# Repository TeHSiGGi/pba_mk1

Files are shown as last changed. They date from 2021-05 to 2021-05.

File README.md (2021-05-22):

# PBA MK1

## Introduction

The **P**ortable **B**luetooth **A**mp MK1 is the first iteration of a portable bluetooth amplifier.

The goal was to design a universal base platform for designing bluetooth speaker in a range of small to large power.

The amplifier is meant to be powered by LiPo batteries.

## Repository structure

```text
/pba:mk1
  /docs             # Documentation repository
  /eagle            # Contains eagle files
  /gerber           # Contains gerber board files
  /pdf              # Contains PDF versions of the schematics 
```

## Technical specification

### Power Supply

The power supply provides different voltages for digital and analog purpose.

It provides the following rails:

- `D33` - 3.3V 0.25A Digital - for digital logic and bluetooth module
- `A75` - 7.5V 0.10A Analog - for analog audio processing
- `D120` - 12V 1.00A Digital - Control voltage for Class-D amplifier
- `VAMP` - VBAT - 30V 3.00A - Amplification voltage for Class-D amplifier

The `D33` rail is constantly enabled and provides power for the bluetooth module.

All other rails are enabled on demand by the bluetooth module, via the `EN` signal.

As regulators for all rails expect `VAMP` `LMR50410` are used.

The `VAMP` rail can be varied between `VBAT` and 30V. This is provided by using a `LM5122` boost converter, that will be enabled on demand. If not required, the `LM5122` will go into passthrough mode and disable the boost action. The boost action is controlled via a separate `LVL` signal.

The power supply also provides the capability to charge and use a 4S LiPo battery. Please note: The power supply does **not** provide any balancing or protection circuitry. Those things must be included in your 4S LiPo battery pack.

As charging controller a `LTC4006-6` is used, which incorporates all necessary functionality.
The power supply used to charge the LiPo battery is a 19V external power supply. The input current is limited to 3.07A.

Charging current is limited to 2.00A and the charging timer is configured to approx. 2 hours.

There is currently **no** NTC readout configured in the charging circuit.

As a charger supply, I recommend the use of generic laptop chargers with 19V and 3.54A - they are widely available, reliable and cheap.

### Amplifier and DAC

As amplifiers there are two `TPA3245` used in this project.

The first of them is driven by directly by the `CSR8675` bluetooth chip DAC outputs, using a BTL configuration for two output channels.

The second amplifier is configured in a PBTL configuration and is driven by a `PCM5102` DAC.

The first amplifier should be used for full-range or dedicated mid/migh-range speakers, whereas the second amplifier with its PBTL configuration is meant to drive low-range/subwoofer speakers, since due to its configuration it is able to deliver more current and drive speakers with low impedances.

All analog signals are used differentially to reduce noise and hum. Between the differential DAC output and amplifier inputs there are `TS914` adding amplification to the signals for additional volume.

The amplifiers will automatically be enabled, if music is playing. This is controlled by the `CSR8675` using the `AMP_EN` signal.

There is an additional level detection circuit that will switch the amplifier supply voltage by setting the `LVL` signal to `high`. This allows the amplifier chips to run at a lower voltage for moderate volumes and have enough headroom for high volume music playback. The usage of a higher voltage also allows for better use of higher impedance speakers, such as 8-16Ohms.

The threshold of the level detection can be configured via a potentiometer on the amplifier board.

### Bluetooth

As for bluetooth, the `CSR8675` in form of `BTM-875` modules is used.

That chip provides the following functionality:

- Bluetooth 4.0+ compliance
- Stereo differential analogue audio inputs (used as line-in)
- Stereo differential analogue audio outputs (driving `TPA3245` in BTL configuration)
- I²S output (driving `PCM5102` for second `TPA3245` in PBTL configuration)
- LED and Button GPIOs (3 LEDs and 8 GPIOs are exposed)
- GPIO control for enabling external circuitry (enabling power with `EN` and amplifiers with `AMP_EN`)
- Kalimba DSP (used for crossover and DSP audio processing)
- True Wireless Stereo (can link two amplifiers together playing music in sync)

Software used on the `CSR8675` is configured using the ADK in version 4.1.35.

### Architecture

#### Audio signal paths

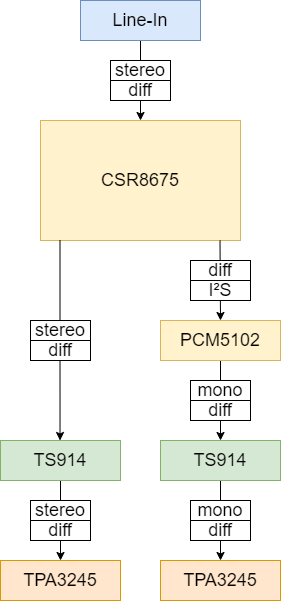
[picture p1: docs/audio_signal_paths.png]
Audio Signal Paths


#### Power paths

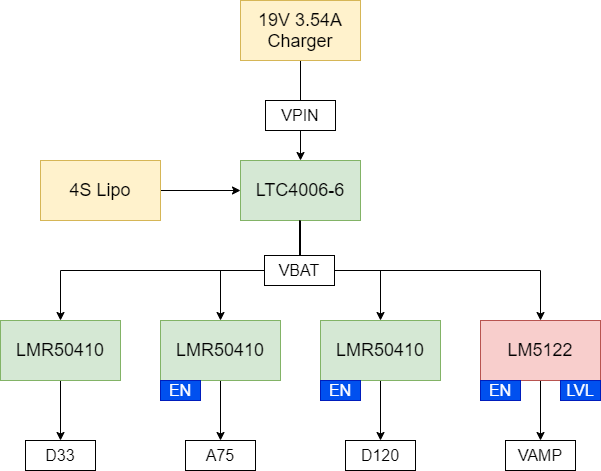
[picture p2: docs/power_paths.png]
Power Paths


#### GPIO to function mapping

|GPIO|Function|Description|
|--|--|--|
|LED0|User interface LED|Can be used to display status messages.|
|LED1|User interface LED|Can be used to display status messages.|
|LED2|User interface LED|Can be used to display status messages.|
|PIO0|User interface GPIO|Can be used to connect a button for user interaction.|
|PIO1|User interface GPIO|Can be used to connect a button for user interaction.|
|PIO2|User interface GPIO|Can be used to connect a button for user interaction.|
|PIO3|User interface GPIO|Can be used to connect a button for user interaction.|
|PIO4|User interface GPIO|Can be used to connect a button for user interaction.|
|PIO5|User interface GPIO|Can be used to connect a button for user interaction.|
|PIO6|User interface GPIO|Can be used to connect a button for user interaction.|
|PIO7|User interface GPIO|Can be used to connect a button for user interaction.|
|PWR|User interface GPIO|Can be used to connect a button for user interaction.|
|PIO10|DETECT|Used to detect plugged in line-in source.|
|PIO11|AMP_EN|Used to enable amplifiers when music is playing.|
|PIO12|EN|Used to enable the power supply.|
|PIO15|I²S DAC enable|Used to enable the external I²S dac if music is playing.|

### Miscellaneous

Schematics and layouts are created using Eagle.

Gerber files provided have been used to create first batch of boards and working instances of the PBA MK1.

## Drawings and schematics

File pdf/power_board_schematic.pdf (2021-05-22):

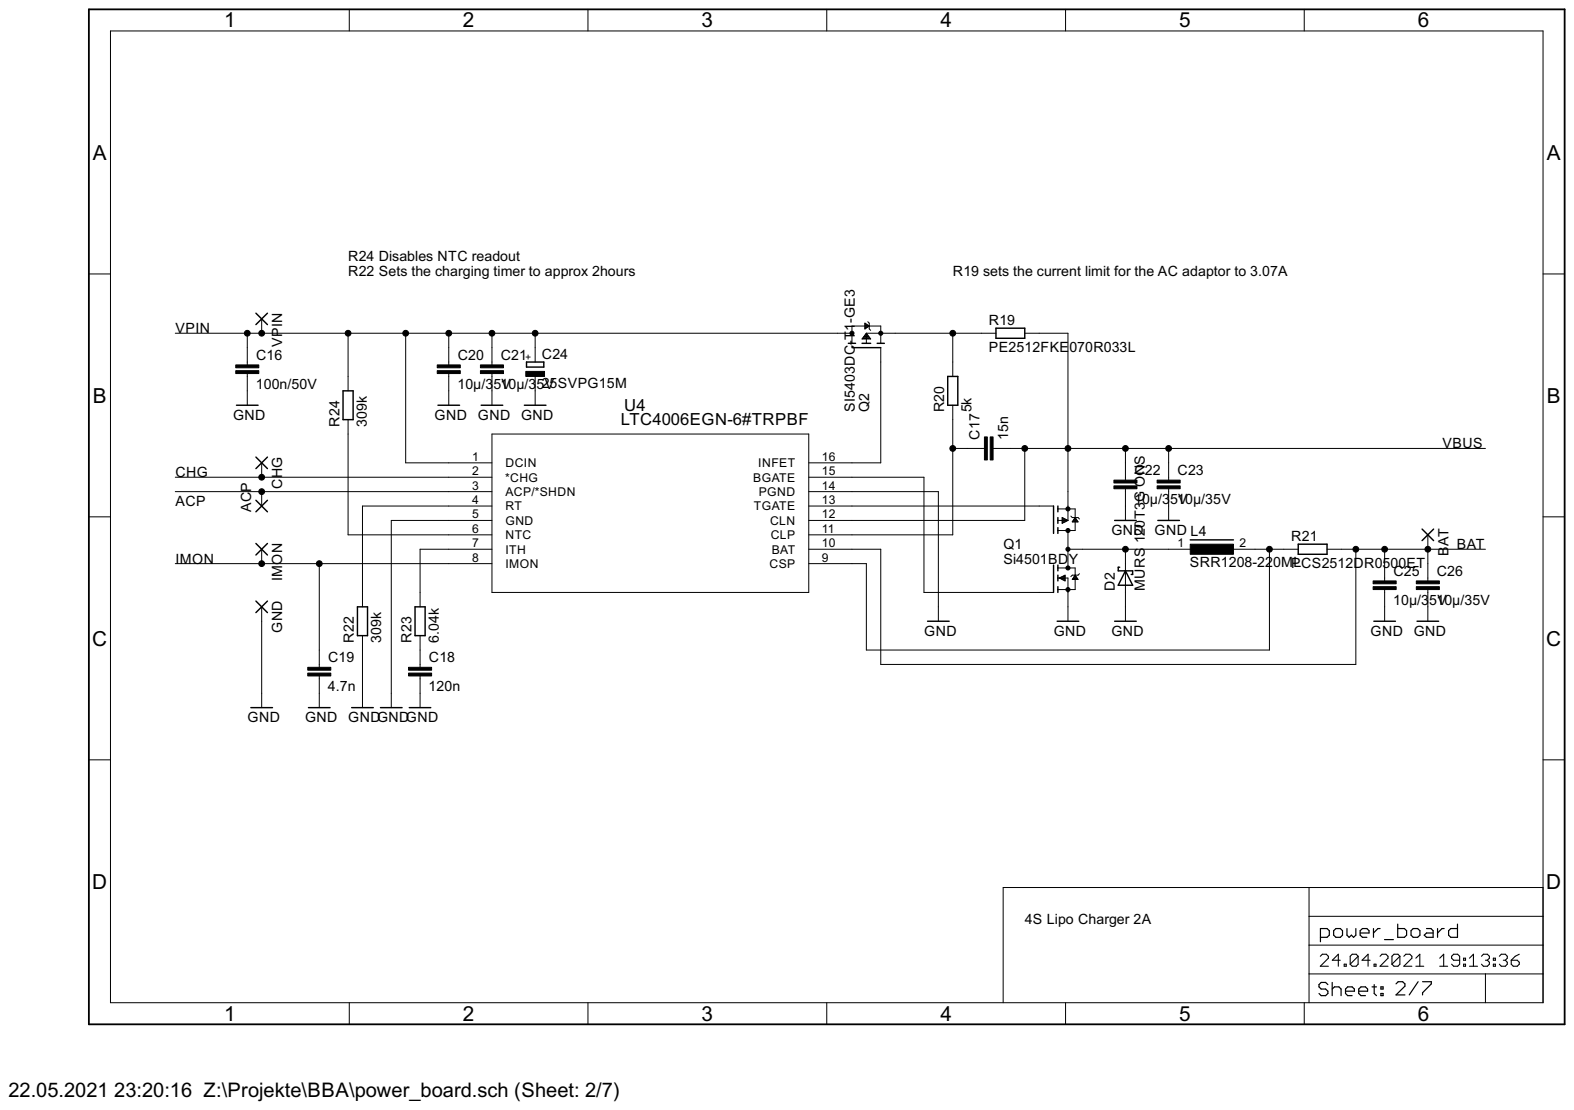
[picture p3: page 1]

13 PGND
12 TGATE

22.05.2021 23:20:16 Z:\Projekte\BBA\power_board.sch (Sheet: 2/7)

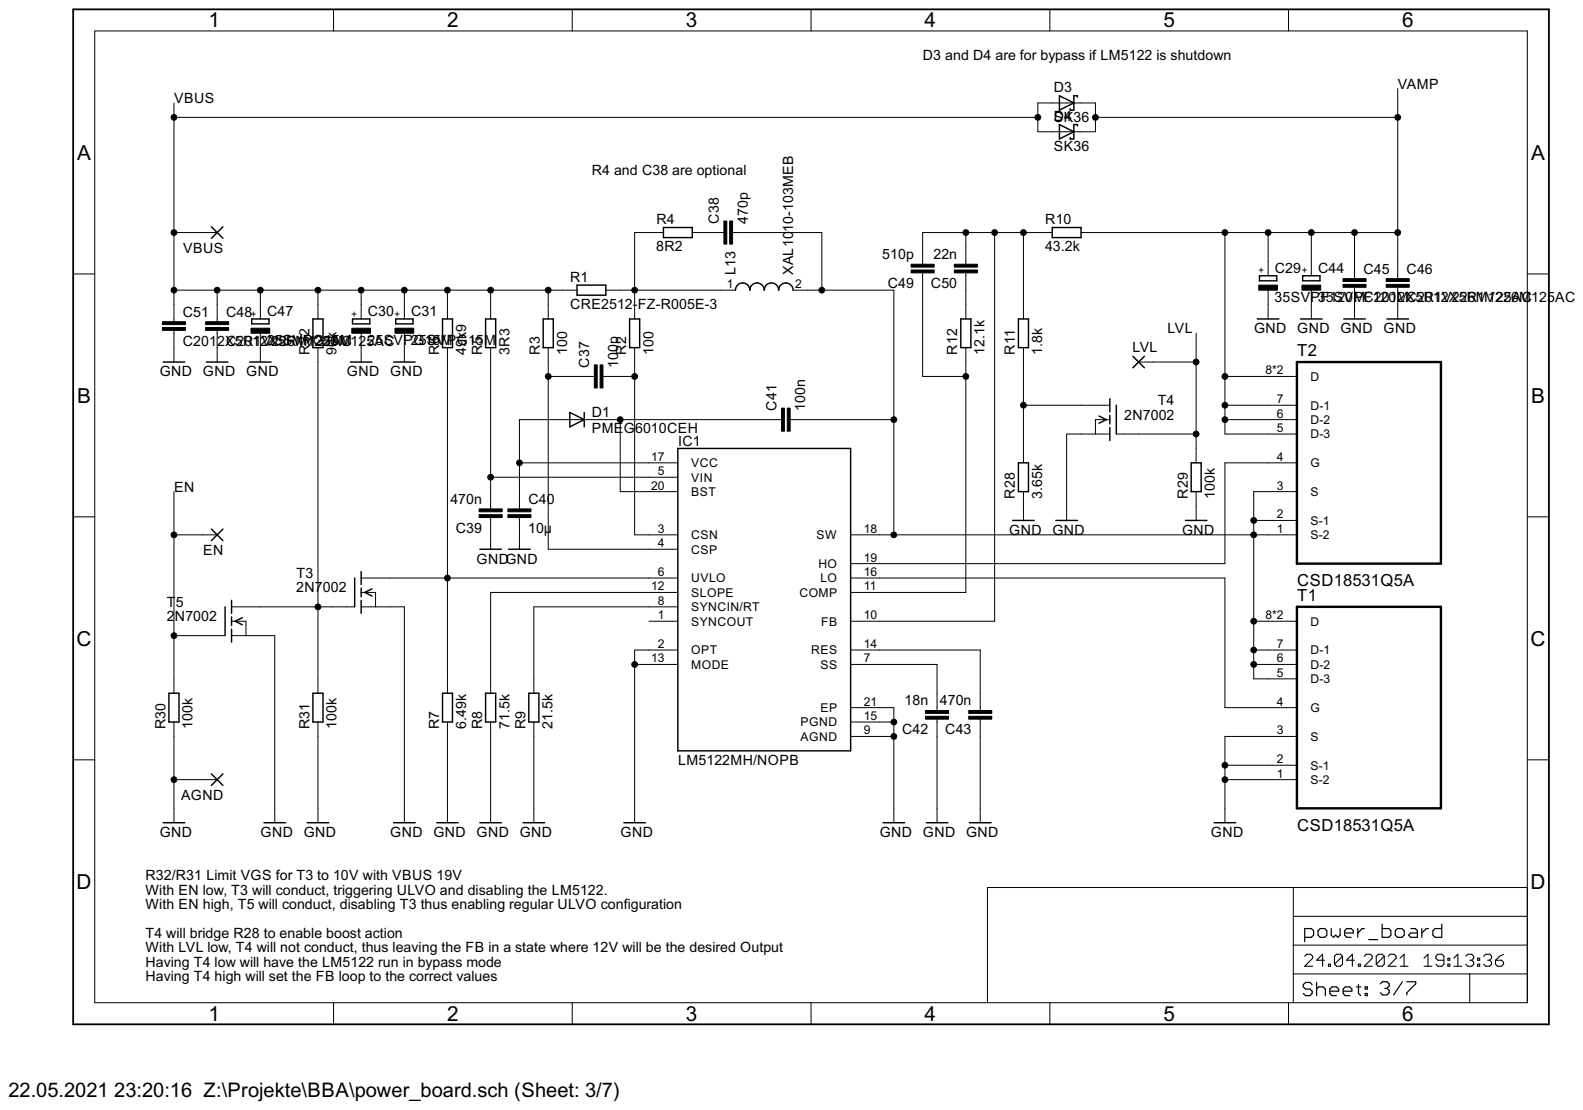
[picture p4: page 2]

D3 and D4 are for bypass if LM5122 is shutdown

GND

R32/R31 Limit VGS for T3 to 10V with VBUS 19V
With EN low, T3 will conduct, triggering ULVO and disabling the LM5122. T4 will bridge R28 to enable boost action With LVL low, T4 will not conduct, thus leaving the FB in a state where 12V will be the desired Output
Having T4 low will have the LM5122 run in bypass mode Having T4 high will set the FB loop to the correct values With EN high, T5 will conduct, disabling T3 thus enabling regular ULVO configuration

22.05.2021 23:20:16 Z:\Projekte\BBA\power_board.sch (Sheet: 3/7)

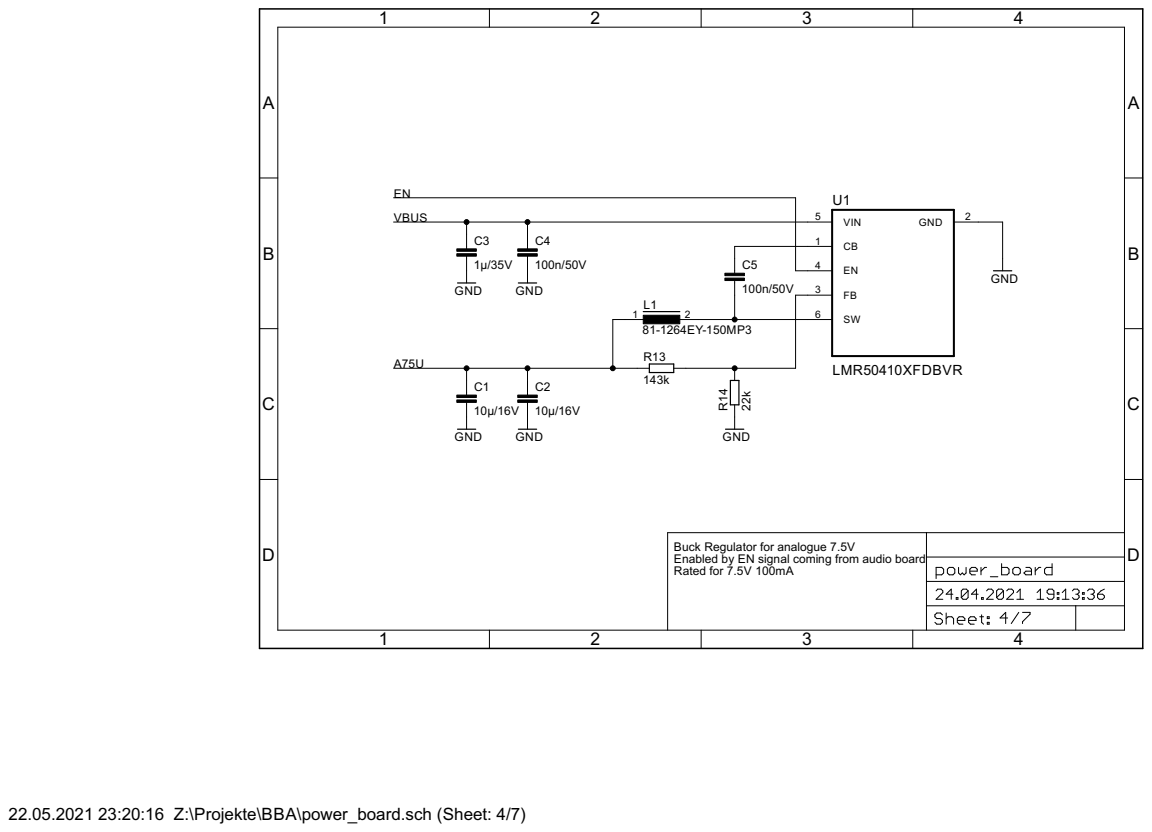
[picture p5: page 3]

Buck Regulator for analogue 7.5V
Enabled by EN signal coming from audio board
Rated for 7.5V 100mA

22.05.2021 23:20:16 Z:\Projekte\BBA\power_board.sch (Sheet: 4/7)

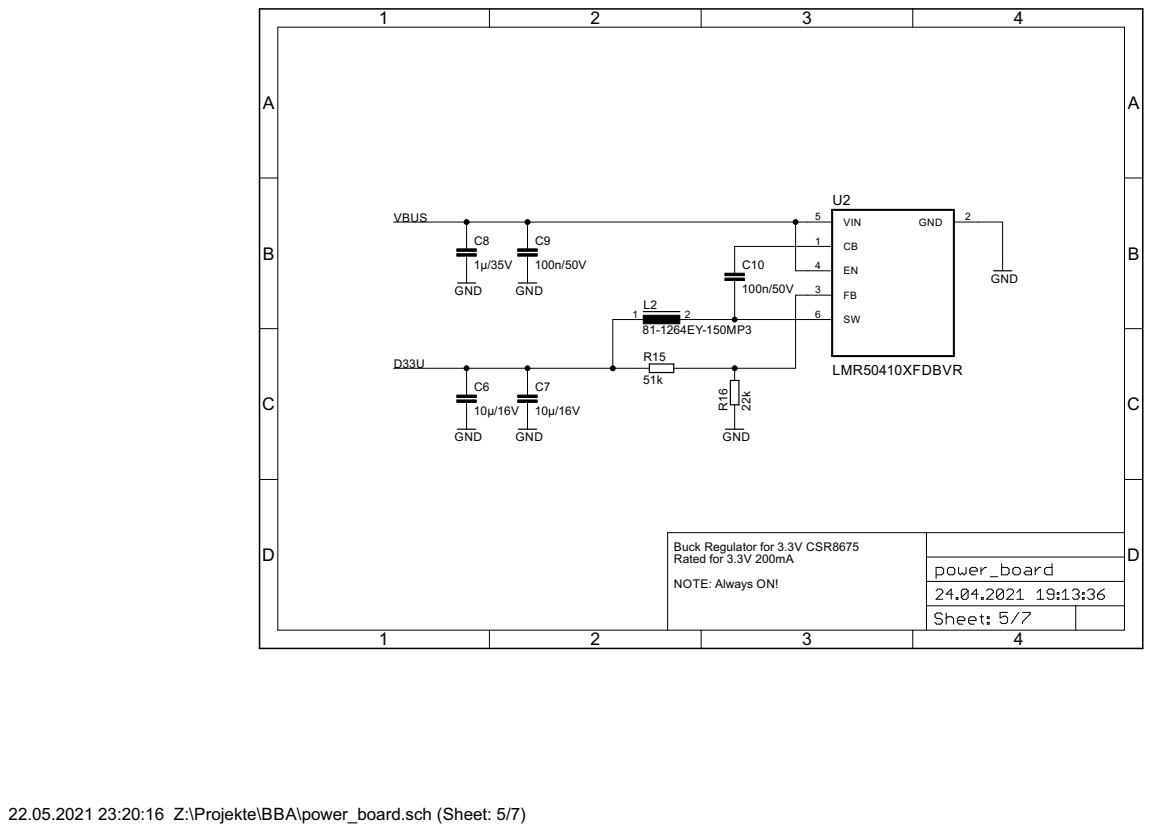
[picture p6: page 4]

22.05.2021 23:20:16 Z:\Projekte\BBA\power_board.sch (Sheet: 5/7)

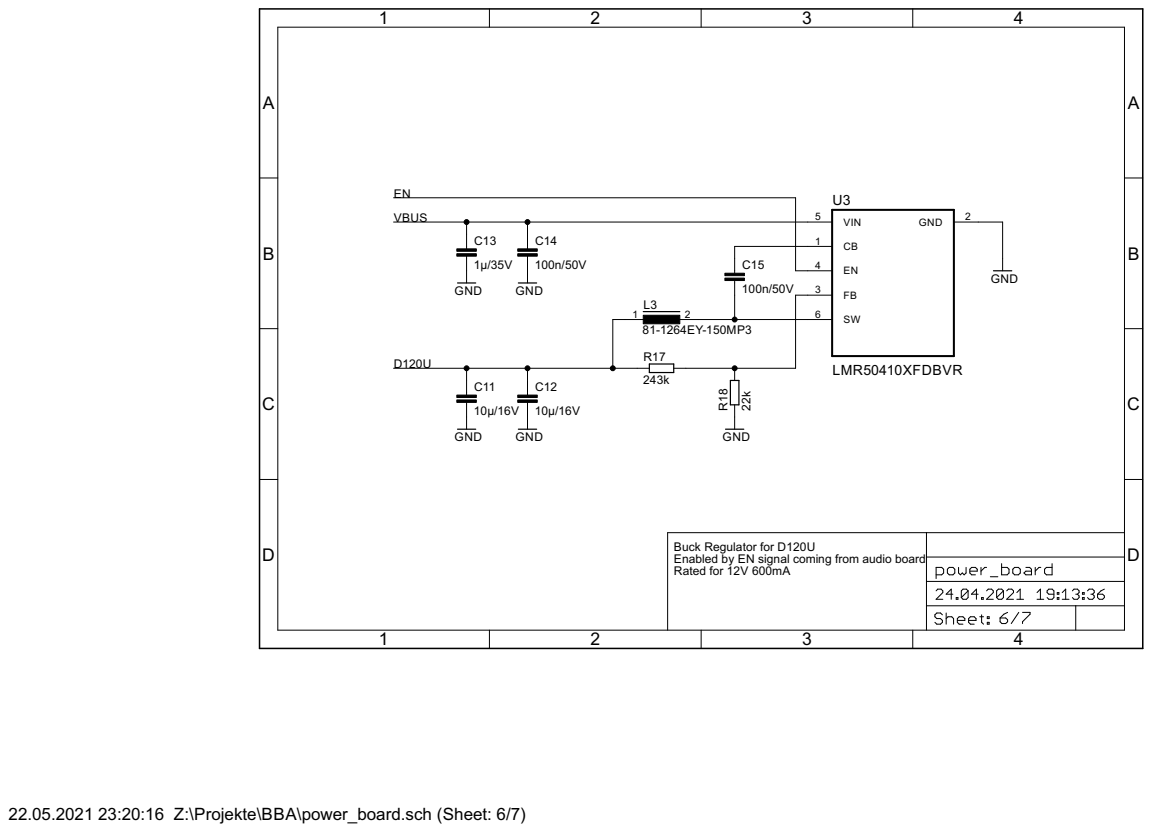
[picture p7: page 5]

Buck Regulator for D120U
Enabled by EN signal coming from audio board
Rated for 12V 600mA

22.05.2021 23:20:16 Z:\Projekte\BBA\power_board.sch (Sheet: 6/7)

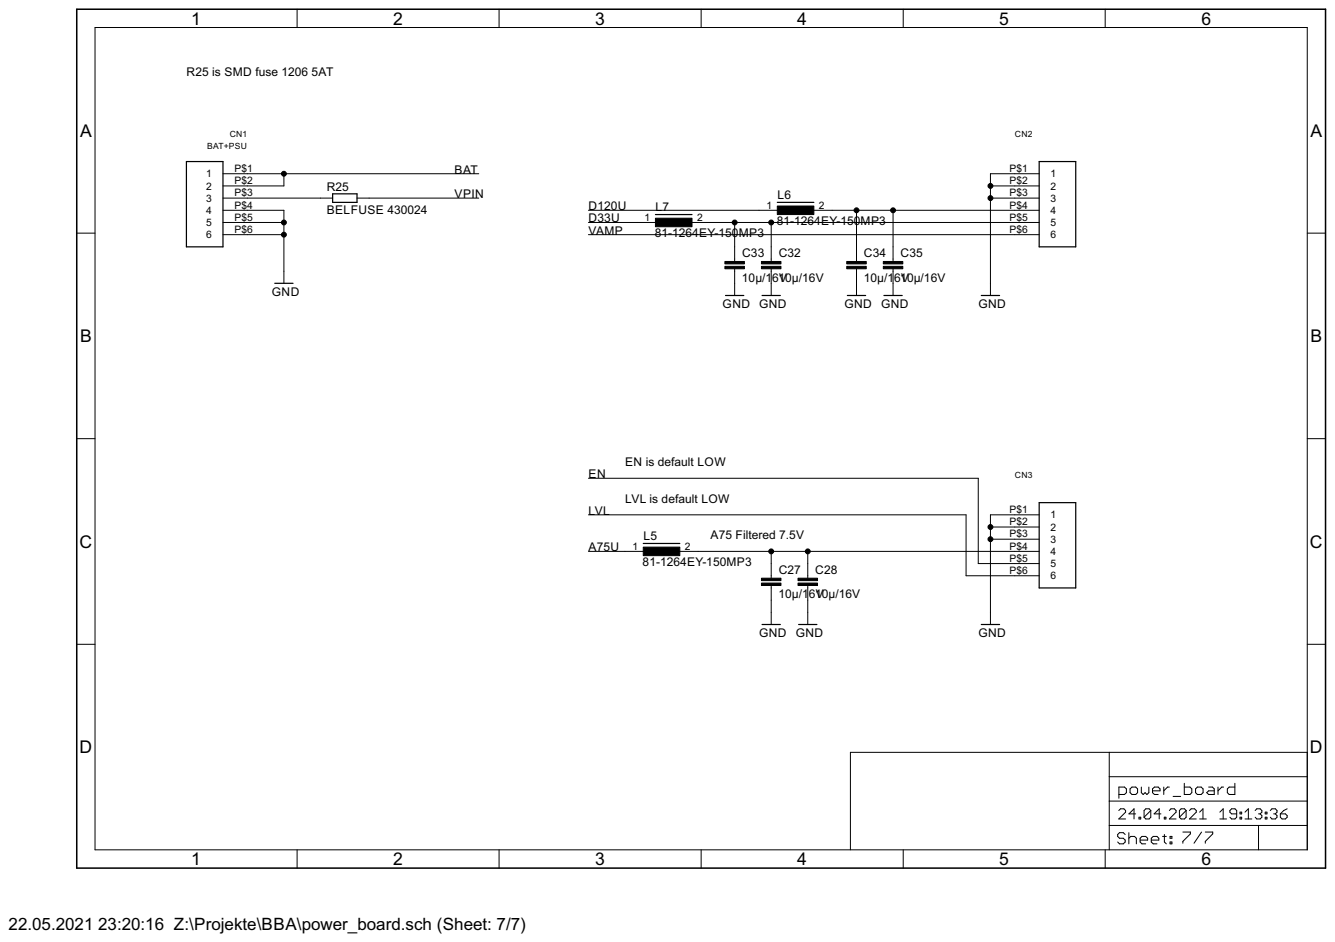
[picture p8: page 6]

EN is default LOW

LVL is default LOW

22.05.2021 23:20:16 Z:\Projekte\BBA\power_board.sch (Sheet: 7/7)

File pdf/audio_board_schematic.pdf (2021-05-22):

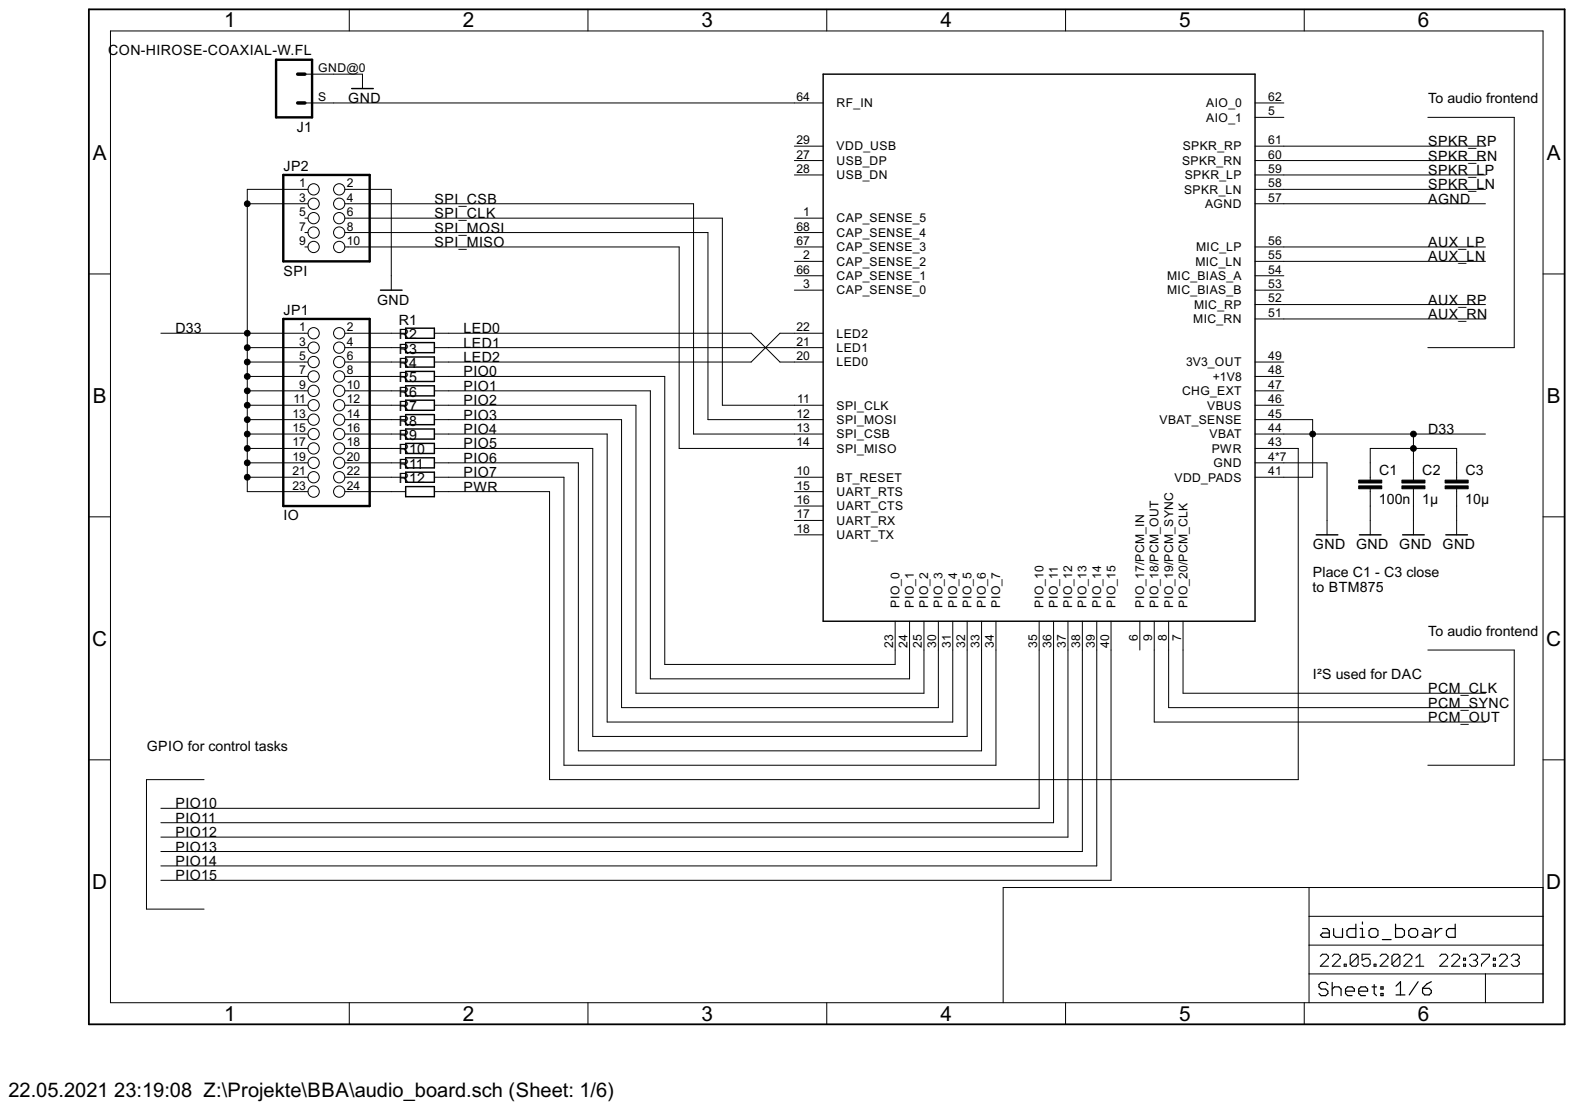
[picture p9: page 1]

CON-HIROSE-COAXIAL-W.FL

I²S used for DAC

GPIO for control tasks

22.05.2021 23:19:08 Z:\Projekte\BBA\audio_board.sch (Sheet: 1/6)

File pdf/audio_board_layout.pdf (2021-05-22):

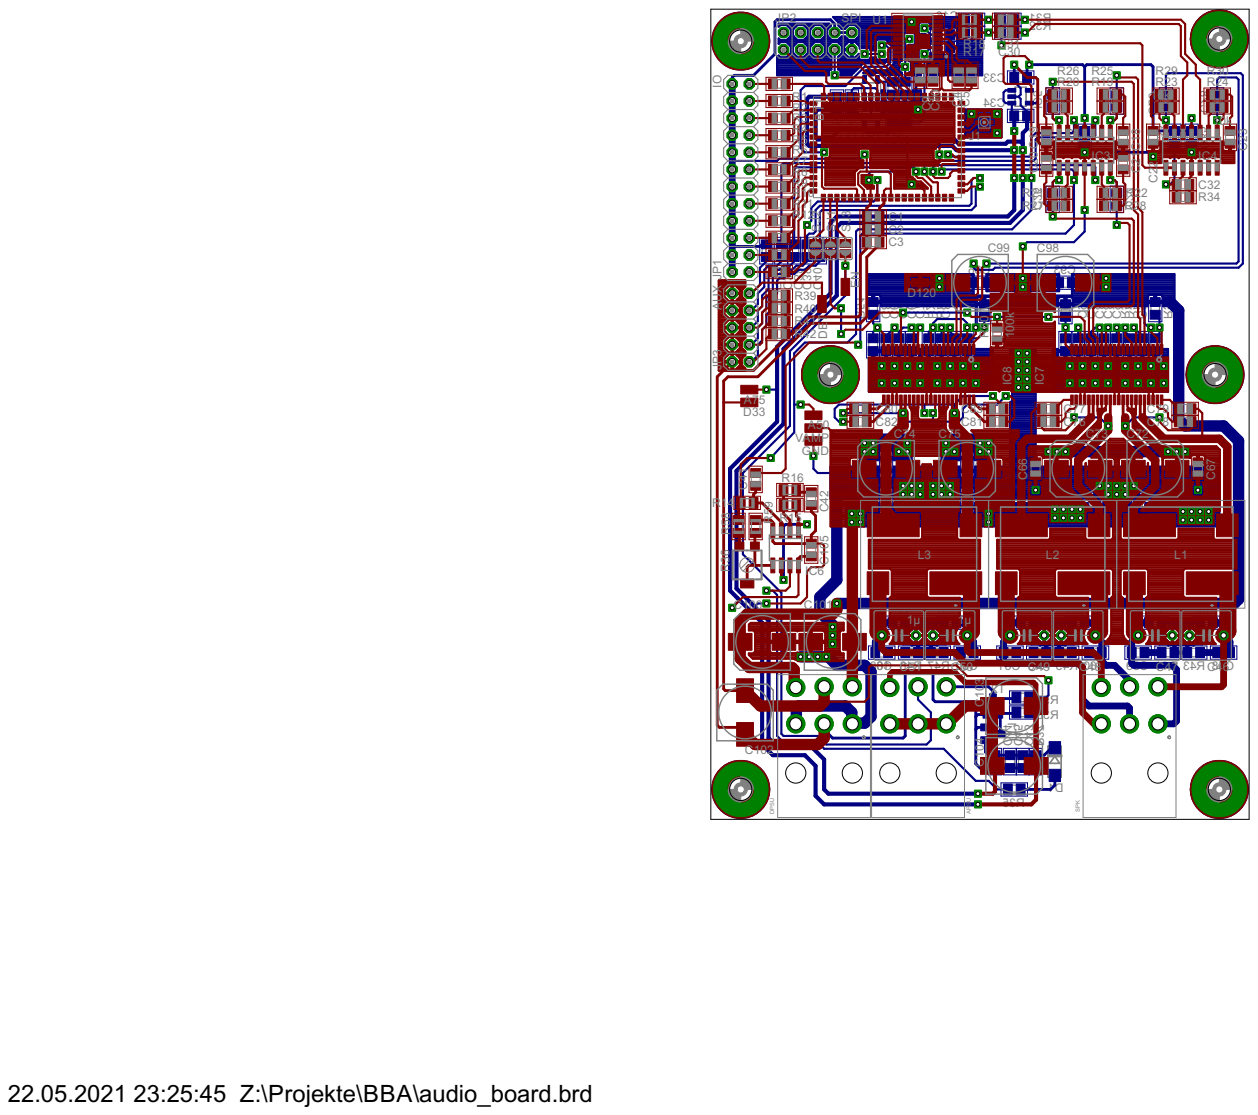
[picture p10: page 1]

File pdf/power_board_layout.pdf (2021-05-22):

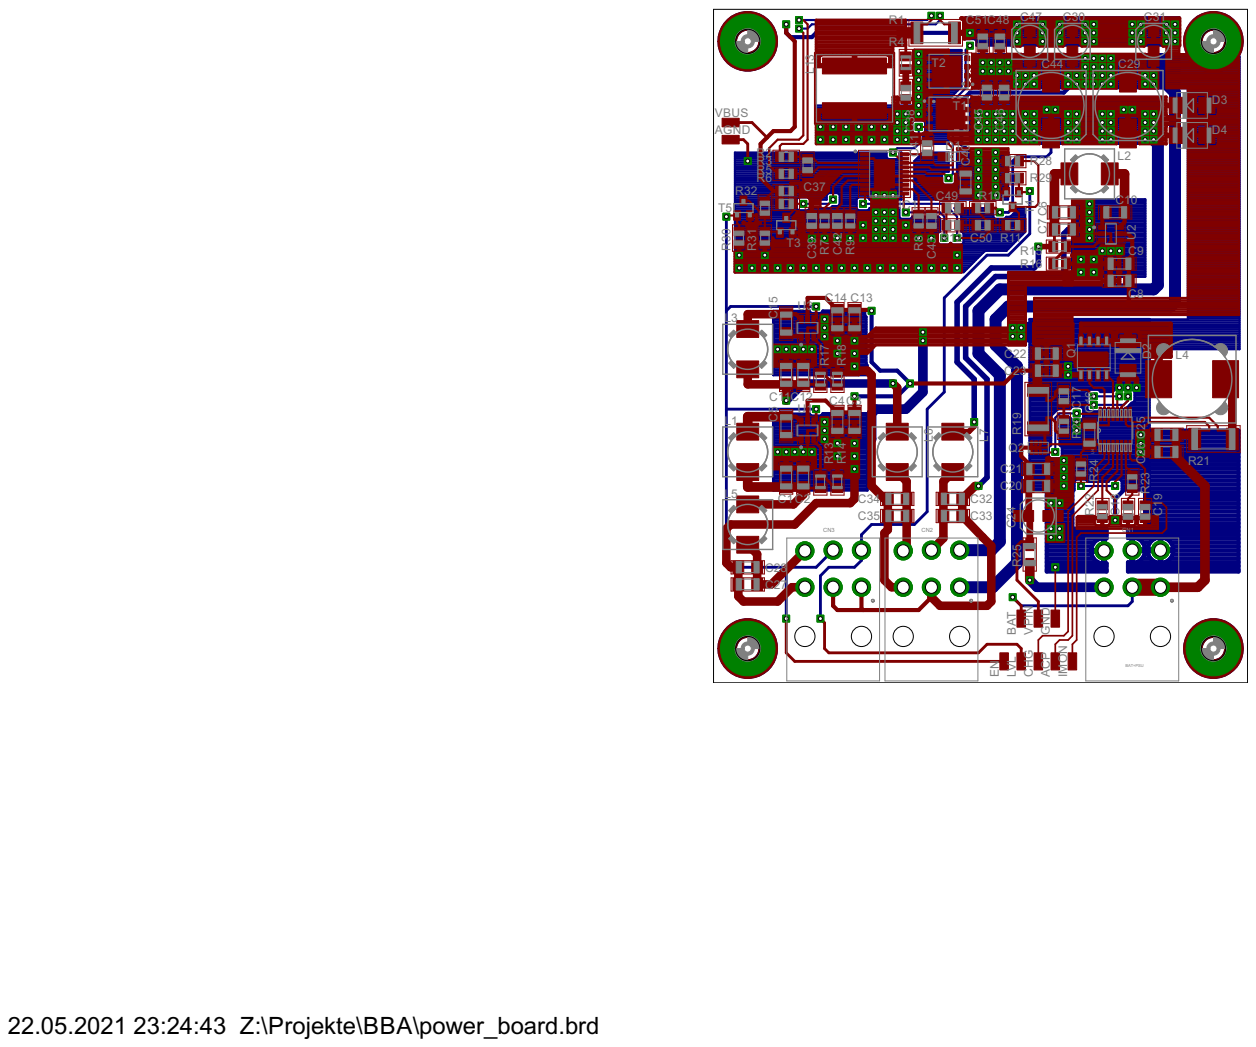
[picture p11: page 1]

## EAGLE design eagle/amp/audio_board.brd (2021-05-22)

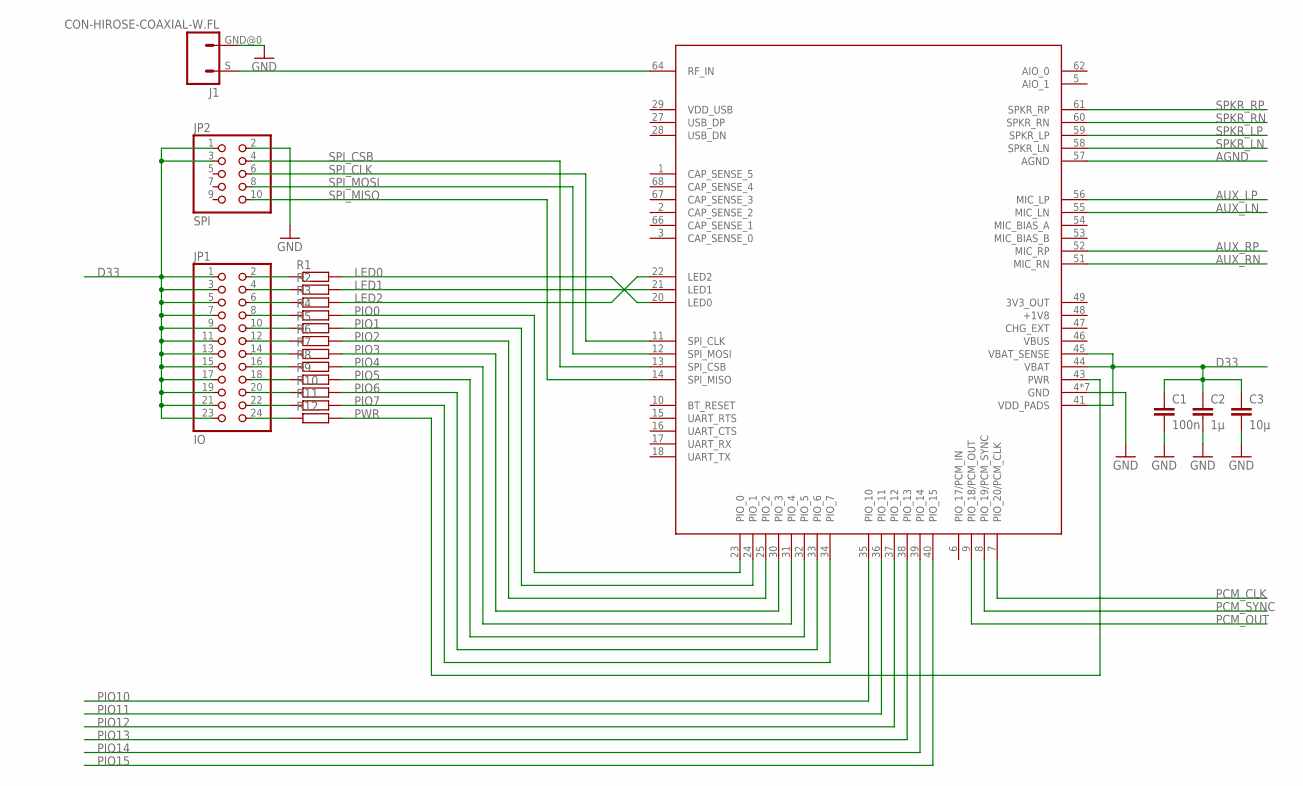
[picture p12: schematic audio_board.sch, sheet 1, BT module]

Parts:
BT1: BTM875-B; BTM875
C1: 100n; C0805
C2: 1µ; C0805
C3: 10µ; C0805
J1: CON-HIROSE-COAXIAL-W.FL; CON-W.FL
JP1: IO; 2X12
JP2: SPI; 2X05
R1, R2, R3, R4, R5, R6, R7, R8, R9, R10, R11, R12: R-EU_R0805; R0805

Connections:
AGND: BT1.57 (AGND)
AUX_LN: BT1.55 (MIC_LN); also elsewhere on the board
AUX_LP: BT1.56 (MIC_LP); also elsewhere on the board
AUX_RN: BT1.51 (MIC_RN); also elsewhere on the board
AUX_RP: BT1.52 (MIC_RP); also elsewhere on the board
D33: BT1.41 (VDD_PADS), BT1.44 (VBAT), BT1.45 (VBAT_SENSE), C1.1, C2.1, C3.1, JP1.1, JP1.3, JP1.5, JP1.7, JP1.9, JP1.11, JP1.13, JP1.15, JP1.17, JP1.19, JP1.21, JP1.23, JP2.1, JP2.3; also elsewhere on the board
GND: BT1.4 (GND), BT1.19 (GND), BT1.26 (GND), BT1.42 (GND), BT1.50 (GND), BT1.63 (GND), BT1.65 (GND), C1.2, C2.2, C3.2, J1.GND@0 (2), JP2.2; also elsewhere on the board
LED0: BT1.20 (LED0), R1.2
LED1: BT1.21 (LED1), R2.2
LED2: BT1.22 (LED2), R3.2
unnamed: BT1.64 (RF_IN), J1.S (1)
unnamed: JP1.2, R1.1
unnamed: JP1.4, R2.1
unnamed: JP1.6, R3.1
unnamed: JP1.8, R4.1
unnamed: JP1.10, R5.1
unnamed: JP1.12, R6.1
unnamed: JP1.14, R7.1
unnamed: JP1.16, R8.1
unnamed: JP1.18, R9.1
unnamed: JP1.20, R10.1
unnamed: JP1.22, R11.1
unnamed: JP1.24, R12.1
PCM_CLK: BT1.7 (PIO_20/PCM_CLK); also elsewhere on the board
PCM_OUT: BT1.9 (PIO_18/PCM_OUT); also elsewhere on the board
PCM_SYNC: BT1.8 (PIO_19/PCM_SYNC); also elsewhere on the board
PIO0: BT1.23 (PIO_0), R4.2
PIO1: BT1.24 (PIO_1), R5.2
PIO2: BT1.25 (PIO_2), R6.2
PIO3: BT1.30 (PIO_3), R7.2
PIO4: BT1.31 (PIO_4), R8.2
PIO5: BT1.32 (PIO_5), R9.2
PIO6: BT1.33 (PIO_6), R10.2
PIO7: BT1.34 (PIO_7), R11.2
PIO10: BT1.35 (PIO_10); also elsewhere on the board
PIO11: BT1.36 (PIO_11); also elsewhere on the board
PIO12: BT1.37 (PIO_12); also elsewhere on the board
PIO13: BT1.38 (PIO_13)
PIO14: BT1.39 (PIO_14)
PIO15: BT1.40 (PIO_15); also elsewhere on the board
PWR: BT1.43 (PWR), R12.2
SPI_CLK: BT1.11 (SPI_CLK), JP2.6
SPI_CSB: BT1.13 (SPI_CSB), JP2.4
SPI_MISO: BT1.14 (SPI_MISO), JP2.10
SPI_MOSI: BT1.12 (SPI_MOSI), JP2.8
SPKR_LN: BT1.58 (SPKR_LN); also elsewhere on the board
SPKR_LP: BT1.59 (SPKR_LP); also elsewhere on the board
SPKR_RN: BT1.60 (SPKR_RN); also elsewhere on the board
SPKR_RP: BT1.61 (SPKR_RP); also elsewhere on the board

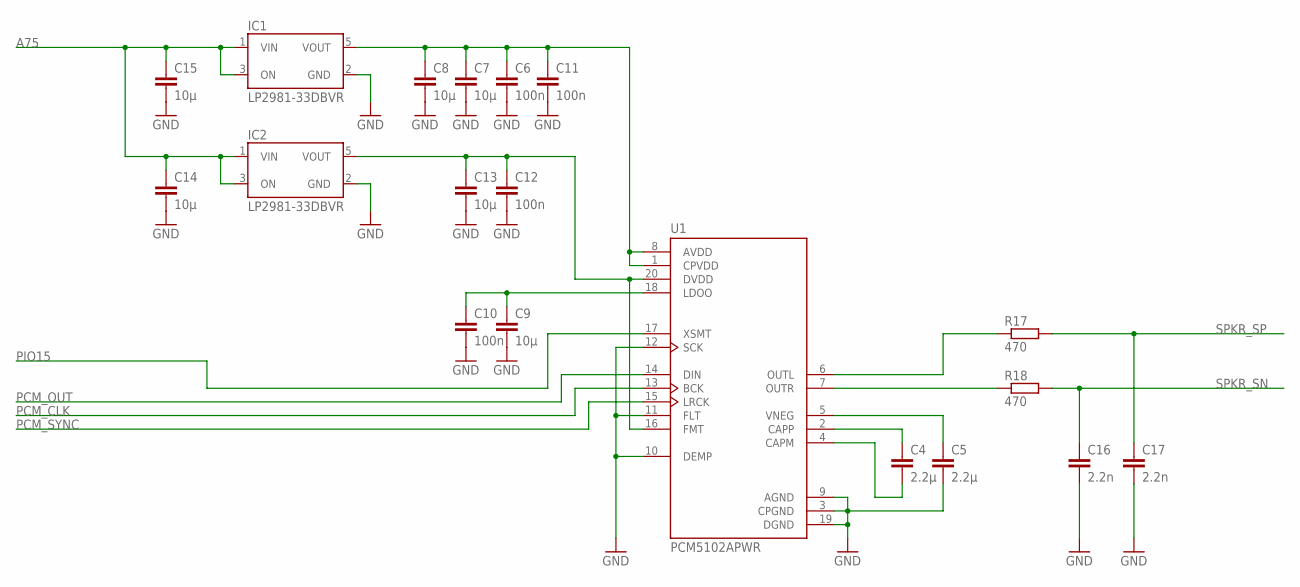
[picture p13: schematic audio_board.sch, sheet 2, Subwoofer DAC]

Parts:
C4, C5: 2.2µ; C0805
C6, C10, C11, C12: 100n; C0805
C7, C8, C9, C13, C14, C15: 10µ; C0805
C16, C17: 2.2n; C0805
IC1, IC2: LP2981-33DBVR; SOT23-5
R17, R18: 470; M0805
U1: PCM5102APWR; SOP65P640X120-20N

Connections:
A33DAC: C6.1, C7.1, C8.1, C11.1, IC1.5 (VOUT), U1.1 (CPVDD), U1.8 (AVDD)
A75: C14.1, C15.1, IC1.1 (VIN), IC1.3 (ON), IC2.1 (VIN), IC2.3 (ON); also elsewhere on the board
D33DAC: C12.1, C13.1, IC2.5 (VOUT), U1.16 (FMT), U1.20 (DVDD)
GND: C5.2, C6.2, C7.2, C8.2, C9.2, C10.2, C11.2, C12.2, C13.2, C14.2, C15.2, C16.2, C17.2, IC1.2 (GND), IC2.2 (GND), U1.3 (CPGND), U1.9 (AGND), U1.10 (DEMP), U1.11 (FLT), U1.12 (SCK), U1.19 (DGND); also elsewhere on the board
unnamed: C4.1, U1.2 (CAPP)
unnamed: C4.2, U1.4 (CAPM)
unnamed: C5.1, U1.5 (VNEG)
unnamed: C9.1, C10.1, U1.18 (LDOO)
unnamed: R18.1, U1.7 (OUTR)
unnamed: R17.1, U1.6 (OUTL)
PCM_CLK: U1.13 (BCK); also elsewhere on the board
PCM_OUT: U1.14 (DIN); also elsewhere on the board
PCM_SYNC: U1.15 (LRCK); also elsewhere on the board
PIO15: U1.17 (XSMT); also elsewhere on the board
SPKR_SN: C16.1, R18.2; also elsewhere on the board
SPKR_SP: C17.1, R17.2; also elsewhere on the board

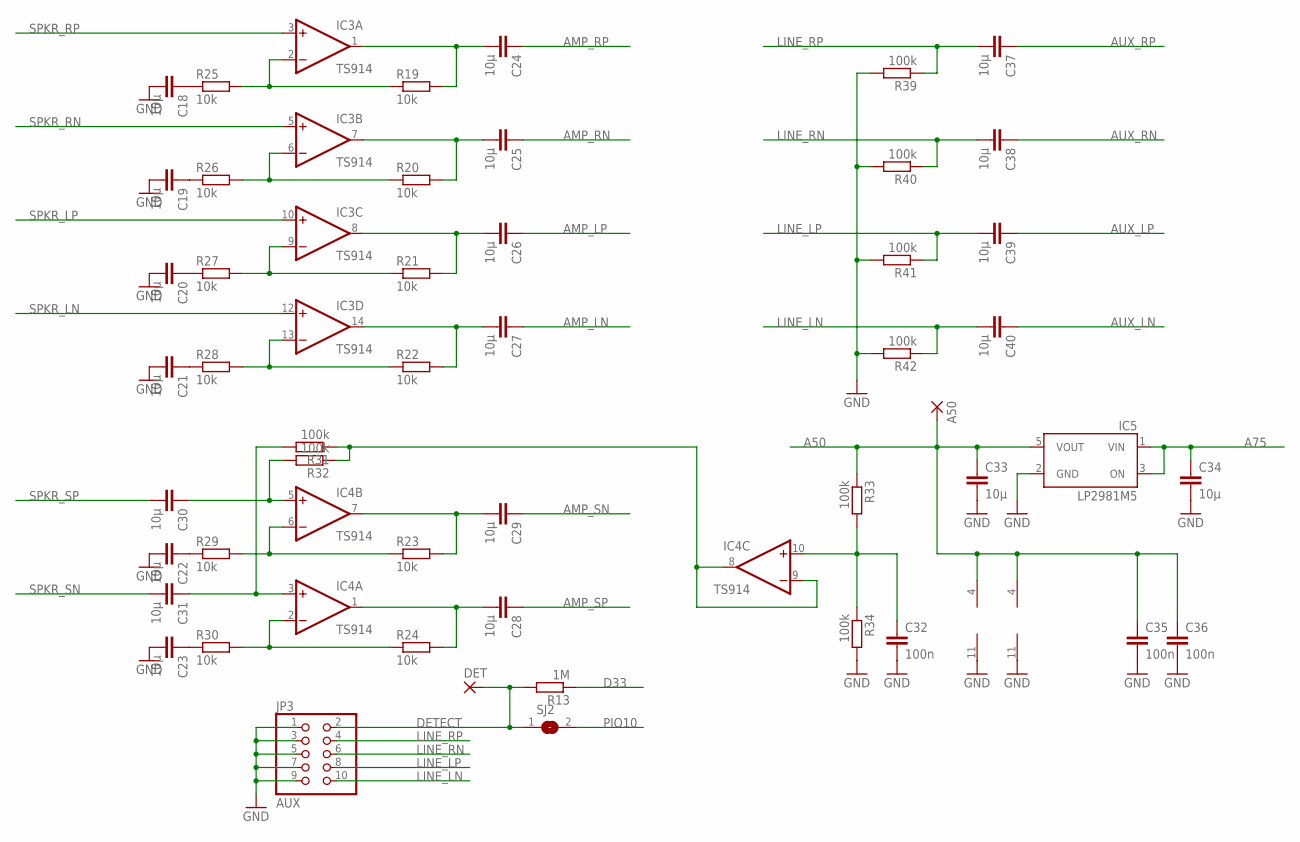
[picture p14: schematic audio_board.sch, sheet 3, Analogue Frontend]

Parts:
A50: SMD2; SMD1,27-2,54
C18, C19, C20, C21, C22, C23, C24, C25, C26, C27, C28, C29, C30, C31, C33, C34, C37, C38, C39, C40: 10µ; C0805
C32, C35, C36: 100n; C0805
DET: SMD2; SMD1,27-2,54
IC3, IC4: TS914; SO14
IC5: LP2981M5; SOT23-5
JP3: AUX; 2X05
R13: 1M; R0805
R19, R20, R21, R22, R23, R24, R25, R26, R27, R28, R29, R30: 10k; R0805
R31, R32, R33, R34, R39, R40, R41, R42: 100k; R0805
SJ2: SJ

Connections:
A25BIAS: IC4.8 (OUT), IC4.9 (-IN), R31.1, R32.1
A50: A50.1, C33.1, C35.1, C36.1, IC3.4 (V+), IC4.4 (V+), IC5.5 (VOUT), R33.1; also elsewhere on the board
A75: C34.1, IC5.1 (VIN), IC5.3 (ON); also elsewhere on the board
AMP_LN: C27.1; also elsewhere on the board
AMP_LP: C26.1; also elsewhere on the board
AMP_RN: C25.1; also elsewhere on the board
AMP_RP: C24.1; also elsewhere on the board
AMP_SN: C29.1; also elsewhere on the board
AMP_SP: C28.1; also elsewhere on the board
AUX_LN: C40.1; also elsewhere on the board
AUX_LP: C39.1; also elsewhere on the board
AUX_RN: C38.1; also elsewhere on the board
AUX_RP: C37.1; also elsewhere on the board
D33: R13.1; also elsewhere on the board
DETECT: DET.1, JP3.2, R13.2, SJ2.1
GND: C18.2, C19.2, C20.2, C21.2, C22.2, C23.2, C32.2, C33.2, C34.2, C35.2, C36.2, IC3.11 (V-), IC4.11 (V-), IC5.2 (GND), JP3.1, JP3.3, JP3.5, JP3.7, JP3.9, R34.2, R39.2, R40.2, R41.2, R42.2; also elsewhere on the board
LINE_LN: C40.2, JP3.10, R42.1
LINE_LP: C39.2, JP3.8, R41.1
LINE_RN: C38.2, JP3.6, R40.1
LINE_RP: C37.2, JP3.4, R39.1
unnamed: C18.1, R25.1
unnamed: C19.1, R26.1
unnamed: C20.1, R27.1
unnamed: C21.1, R28.1
unnamed: C22.1, R29.1
unnamed: C23.1, R30.1
unnamed: IC4.2 (-IN), R24.1, R30.2
unnamed: IC4.6 (-IN), R23.1, R29.2
unnamed: IC3.13 (-IN), R22.1, R28.2
unnamed: IC3.9 (-IN), R21.1, R27.2
unnamed: IC3.6 (-IN), R20.1, R26.2
unnamed: IC3.2 (-IN), R19.1, R25.2
unnamed: C24.2, IC3.1 (OUT), R19.2
unnamed: C25.2, IC3.7 (OUT), R20.2
unnamed: C26.2, IC3.8 (OUT), R21.2
unnamed: C27.2, IC3.14 (OUT), R22.2
unnamed: C29.2, IC4.7 (OUT), R23.2
unnamed: C28.2, IC4.1 (OUT), R24.2
unnamed: C32.1, IC4.10 (+IN), R33.2, R34.1
unnamed: C31.1, IC4.3 (+IN), R31.2
unnamed: C30.1, IC4.5 (+IN), R32.2
PIO10: SJ2.2; also elsewhere on the board
SPKR_LN: IC3.12 (+IN); also elsewhere on the board
SPKR_LP: IC3.10 (+IN); also elsewhere on the board
SPKR_RN: IC3.5 (+IN); also elsewhere on the board
SPKR_RP: IC3.3 (+IN); also elsewhere on the board
SPKR_SN: C31.2; also elsewhere on the board
SPKR_SP: C30.2; also elsewhere on the board

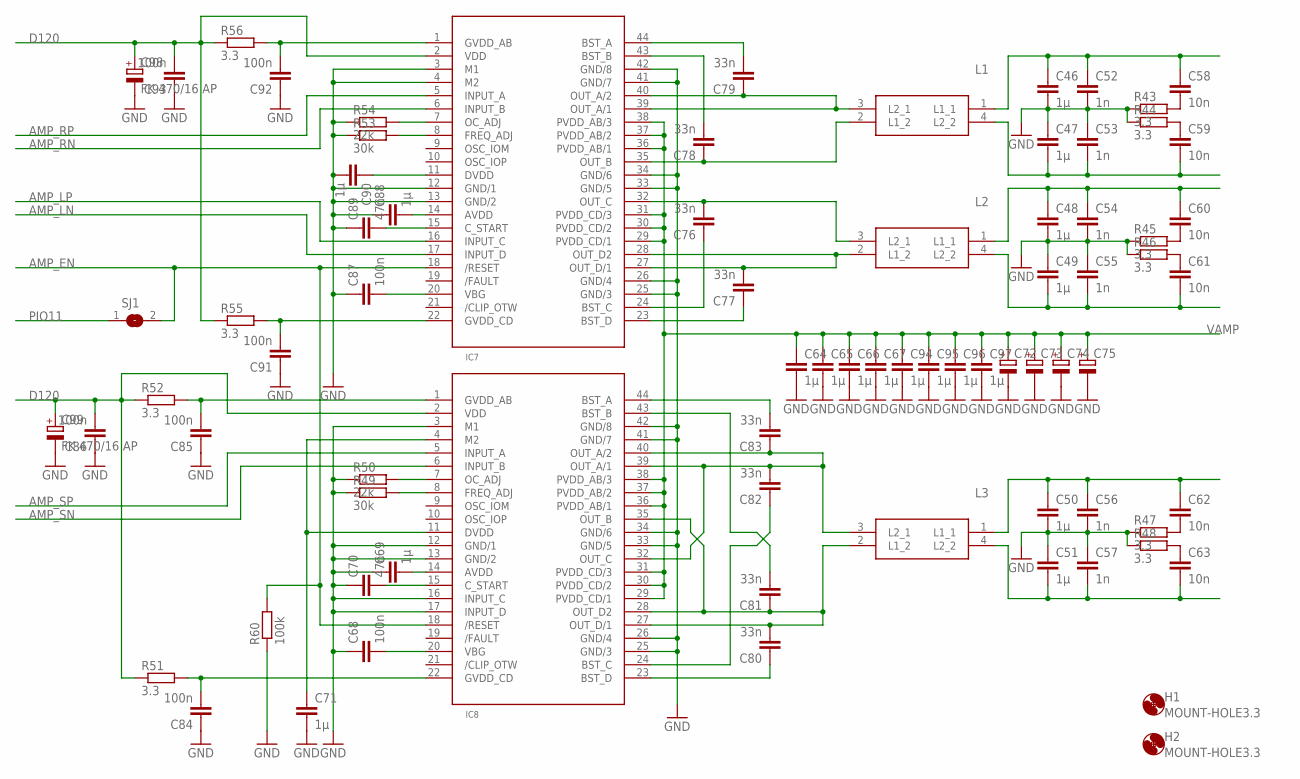
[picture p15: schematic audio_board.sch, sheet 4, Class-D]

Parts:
C46, C47, C48, C49, C50, C51: 1µ; C050-075X075
C52, C53, C54, C55, C56, C57: 1n; C0805
C58, C59, C60, C61, C62, C63: 10n; C0805
C64, C65, C66, C67, C69, C71, C88, C90, C94, C95, C96, C97: 1µ; C0805
C68, C84, C85, C86, C87, C91, C92, C93: 100n; C0805
C70, C89: 47n; C0805
C72, C73, C74, C75: CPOL-EU153CLV-0810; 153CLV-0810
C76, C77, C78, C79, C80, C81, C82, C83: 33n; C0805
C98, C99: FK 470/16 AP; 153CLV-0810
H1, H2: MOUNT-HOLE3.3; 3,3
IC7, IC8: TPA3255; POWERPAD-TSSOP-44
L1, L2, L3: UA8014-ALD; UA8014ALD
R43, R44, R45, R46, R47, R48, R51, R52, R55, R56: 3.3; R0805
R49, R53: 30k; R0805
R50, R54: 22k; R0805
R60: 100k; R0805
SJ1: SJ

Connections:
AMP_EN: IC7.18 (/RESET), IC8.18 (/RESET), R60.2, SJ1.2
AMP_LN: IC7.17 (INPUT_D); also elsewhere on the board
AMP_LP: IC7.16 (INPUT_C); also elsewhere on the board
AMP_RN: IC7.6 (INPUT_B); also elsewhere on the board
AMP_RP: IC7.5 (INPUT_A); also elsewhere on the board
AMP_SN: IC8.6 (INPUT_B); also elsewhere on the board
AMP_SP: IC8.5 (INPUT_A); also elsewhere on the board
D120: C86.2, C93.2, C98.+, C99.+, IC7.2 (VDD), IC8.2 (VDD), R51.1, R52.1, R55.1, R56.1; also elsewhere on the board
GND: C46.2, C47.1, C48.2, C49.1, C50.2, C51.1, C52.2, C53.1, C54.2, C55.1, C56.2, C57.1, C64.2, C65.2, C66.2, C67.2, C68.1, C69.1, C70.1, C71.2, C72.-, C73.-, C74.-, C75.-, C84.1, C85.1, C86.1, C87.1, C88.1, C89.1, C90.2, C91.1, C92.1, C93.1, C94.2, C95.2, C96.2, C97.2, C98.-, C99.-, IC7.3 (M1), IC7.4 (M2), IC7.12 (GND/1), IC7.13 (GND/2), IC7.25 (GND/3), IC7.26 (GND/4), IC7.33 (GND/5), IC7.34 (GND/6), IC7.41 (GND/7), IC7.42 (GND/8), IC8.3 (M1), IC8.12 (GND/1), IC8.13 (GND/2), IC8.16 (INPUT_C), IC8.17 (INPUT_D), IC8.25 (GND/3), IC8.26 (GND/4), IC8.33 (GND/5), IC8.34 (GND/6), IC8.41 (GND/7), IC8.42 (GND/8), R43.1, R44.1, R45.1, R46.1, R47.1, R48.1, R49.1, R50.1, R53.1, R54.1, R60.1; also elsewhere on the board
LN: C49.2, C55.2, C61.2, L2.4 (L2_2); also elsewhere on the board
LP: C48.1, C54.1, C60.1, L2.1 (L1_1); also elsewhere on the board
unnamed: C79.1, IC7.39 (OUT_A/1), IC7.40 (OUT_A/2), L1.3 (L2_1)
unnamed: C78.1, IC7.35 (OUT_B), L1.2 (L1_2)
unnamed: C77.2, IC7.27 (OUT_D/1), IC7.28 (OUT_D2), L2.2 (L1_2)
unnamed: C76.2, IC7.32 (OUT_C), L2.3 (L2_1)
unnamed: C58.2, R43.2
unnamed: C59.1, R44.2
unnamed: C60.2, R45.2
unnamed: C61.1, R46.2
unnamed: C62.2, R47.2
unnamed: C63.1, R48.2
unnamed: C79.2, IC7.44 (BST_A)
unnamed: C78.2, IC7.43 (BST_B)
unnamed: C76.1, IC7.24 (BST_C)
unnamed: C71.1, IC8.4 (M2), IC8.11 (DVDD)
unnamed: IC8.7 (OC_ADJ), R50.2
unnamed: C77.1, IC7.23 (BST_D)
unnamed: C82.2, C83.1, IC8.32 (OUT_C), IC8.39 (OUT_A/1), IC8.40 (OUT_A/2), L3.3 (L2_1)
unnamed: C80.2, C81.1, IC8.27 (OUT_D/1), IC8.28 (OUT_D2), IC8.35 (OUT_B), L3.2 (L1_2)
unnamed: C83.2, IC8.44 (BST_A)
unnamed: C80.1, IC8.23 (BST_D)
unnamed: C82.1, IC8.24 (BST_C)
unnamed: C81.2, IC8.43 (BST_B)
unnamed: C68.2, IC8.20 (VBG)
unnamed: C69.2, IC8.14 (AVDD)
unnamed: C70.2, IC8.15 (C_START)
unnamed: IC8.8 (FREQ_ADJ), R49.2
unnamed: C85.2, IC8.1 (GVDD_AB), R52.2
unnamed: C84.2, IC8.22 (GVDD_CD), R51.2
unnamed: C90.1, IC7.11 (DVDD)
unnamed: C87.2, IC7.20 (VBG)
unnamed: C88.2, IC7.14 (AVDD)
unnamed: C89.2, IC7.15 (C_START)
unnamed: IC7.7 (OC_ADJ), R54.2
unnamed: IC7.8 (FREQ_ADJ), R53.2
unnamed: C92.2, IC7.1 (GVDD_AB), R56.2
unnamed: C91.2, IC7.22 (GVDD_CD), R55.2
PIO11: SJ1.1; also elsewhere on the board
RN: C47.2, C53.2, C59.2, L1.4 (L2_2); also elsewhere on the board
RP: C46.1, C52.1, C58.1, L1.1 (L1_1); also elsewhere on the board
SUBN: C51.2, C57.2, C63.2, L3.4 (L2_2); also elsewhere on the board
SUBP: C50.1, C56.1, C62.1, L3.1 (L1_1); also elsewhere on the board
VAMP: C64.1, C65.1, C66.1, C67.1, C72.+, C73.+, C74.+, C75.+, C94.1, C95.1, C96.1, C97.1, IC7.29 (PVDD_CD/1), IC7.30 (PVDD_CD/2), IC7.31 (PVDD_CD/3), IC7.36 (PVDD_AB/1), IC7.37 (PVDD_AB/2), IC7.38 (PVDD_AB/3), IC8.29 (PVDD_CD/1), IC8.30 (PVDD_CD/2), IC8.31 (PVDD_CD/3), IC8.36 (PVDD_AB/1), IC8.37 (PVDD_AB/2), IC8.38 (PVDD_AB/3); also elsewhere on the board

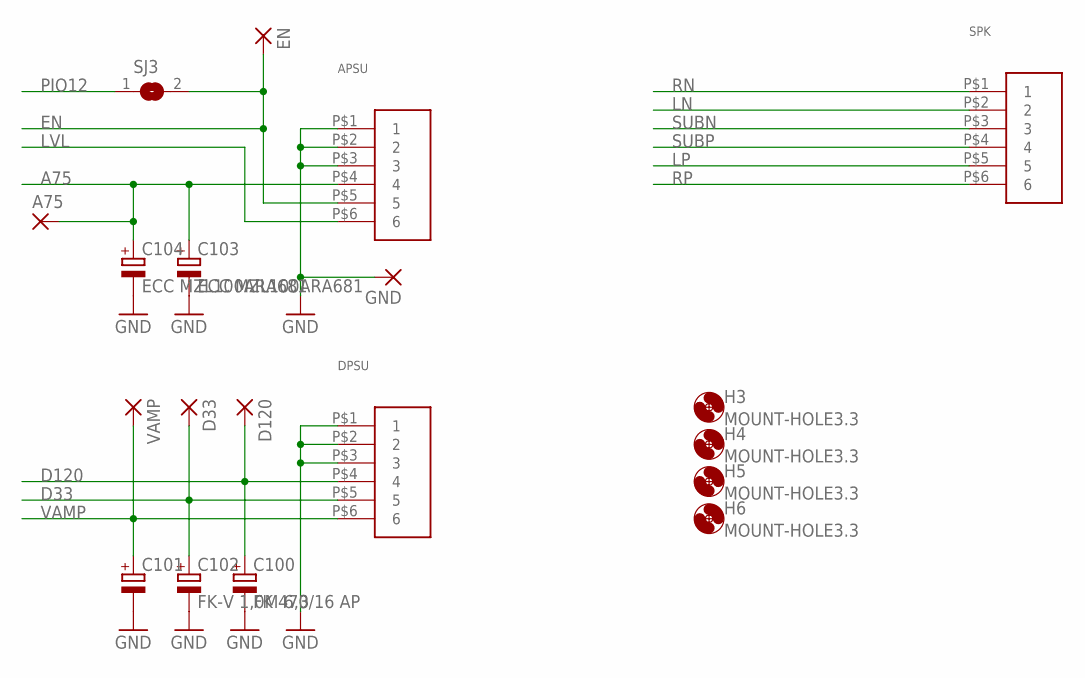
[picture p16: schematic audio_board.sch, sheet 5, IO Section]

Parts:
A75: SMD2; SMD1,27-2,54
APSU: 39-30-1060_BLANK; 5569_6P
C100: FK 470/16 AP; 153CLV-0810
C101: CPOL-EU153CLV-0810; 153CLV-0810
C102: FK-V 1,0M 6,3; 153CLV-0810
C103, C104: ECC MZL100ARA681; 153CLV-0810
D33, D120: SMD2; SMD1,27-2,54
DPSU: 39-30-1060_BLANK; 5569_6P
EN: SMD2; SMD1,27-2,54
GND: SMD2; SMD1,27-2,54
H3, H4, H5, H6: MOUNT-HOLE3.3; 3,3
SJ3: SJ
SPK: 39-30-1060_BLANK; 5569_6P
VAMP: SMD2; SMD1,27-2,54

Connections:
A75: A75.1, APSU.P$4 (4), C103.+, C104.+; also elsewhere on the board
D33: C102.+, D33.1, DPSU.P$5 (5); also elsewhere on the board
D120: C100.+, D120.1, DPSU.P$4 (4); also elsewhere on the board
EN: APSU.P$5 (5), EN.1, SJ3.2
GND: APSU.P$1 (1), APSU.P$2 (2), APSU.P$3 (3), C100.-, C101.-, C102.-, C103.-, C104.-, DPSU.P$1 (1), DPSU.P$2 (2), DPSU.P$3 (3), GND.1; also elsewhere on the board
LN: SPK.P$2 (2); also elsewhere on the board
LP: SPK.P$5 (5); also elsewhere on the board
LVL: APSU.P$6 (6); also elsewhere on the board
PIO12: SJ3.1; also elsewhere on the board
RN: SPK.P$1 (1); also elsewhere on the board
RP: SPK.P$6 (6); also elsewhere on the board
SUBN: SPK.P$3 (3); also elsewhere on the board
SUBP: SPK.P$4 (4); also elsewhere on the board
VAMP: C101.+, DPSU.P$6 (6), VAMP.1; also elsewhere on the board

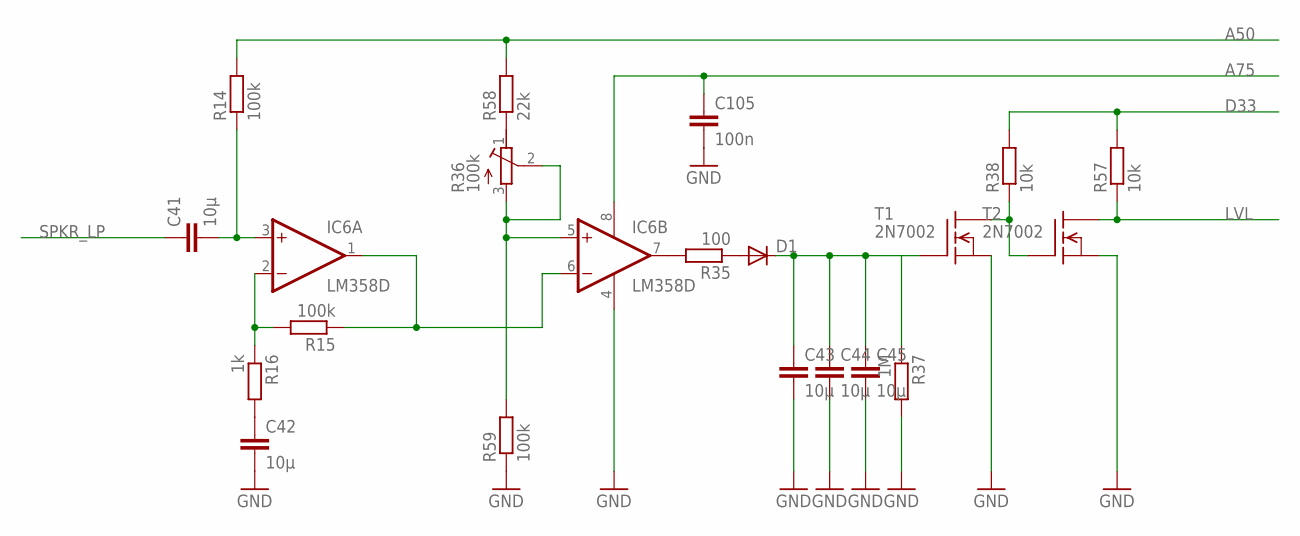
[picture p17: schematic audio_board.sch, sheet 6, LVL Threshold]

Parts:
C41, C42, C43, C44, C45: 10µ; C0805
C105: 100n; C0805
D1: DIODE-DO214AC; DO214AC
IC6: LM358D; SO08
R14, R15, R59: 100k; M0805
R16: 1k; M0805
R35: 100; M0805
R36: 100k; RTRIM3314G
R37: 1M; M0805
R38, R57: 10k; M0805
R58: 22k; M0805
T1, T2: 2N7002; SOT23

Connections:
A50: R14.2, R58.2; also elsewhere on the board
A75: C105.1, IC6.8 (V+); also elsewhere on the board
D33: R38.2, R57.2; also elsewhere on the board
GND: C42.2, C43.2, C44.2, C45.2, C105.2, IC6.4 (V-), R37.2, R59.1, T1.2 (S), T2.2 (S); also elsewhere on the board
LVL: R57.1, T2.3 (D); also elsewhere on the board
unnamed: C41.2, IC6.3 (+IN), R14.1
unnamed: C42.1, R16.2
unnamed: IC6.2 (-IN), R15.2, R16.1
unnamed: IC6.1 (OUT), IC6.6 (-IN), R15.1
unnamed: R38.1, T1.3 (D), T2.1 (G)
unnamed: R36.1 (E), R58.1
unnamed: IC6.7 (OUT), R35.2
unnamed: D1.A, R35.1
unnamed: C43.1, C44.1, C45.1, D1.C, R37.1, T1.1 (G)
unnamed: IC6.5 (+IN), R36.2 (S), R36.3 (A), R59.2
SPKR_LP: C41.1; also elsewhere on the board

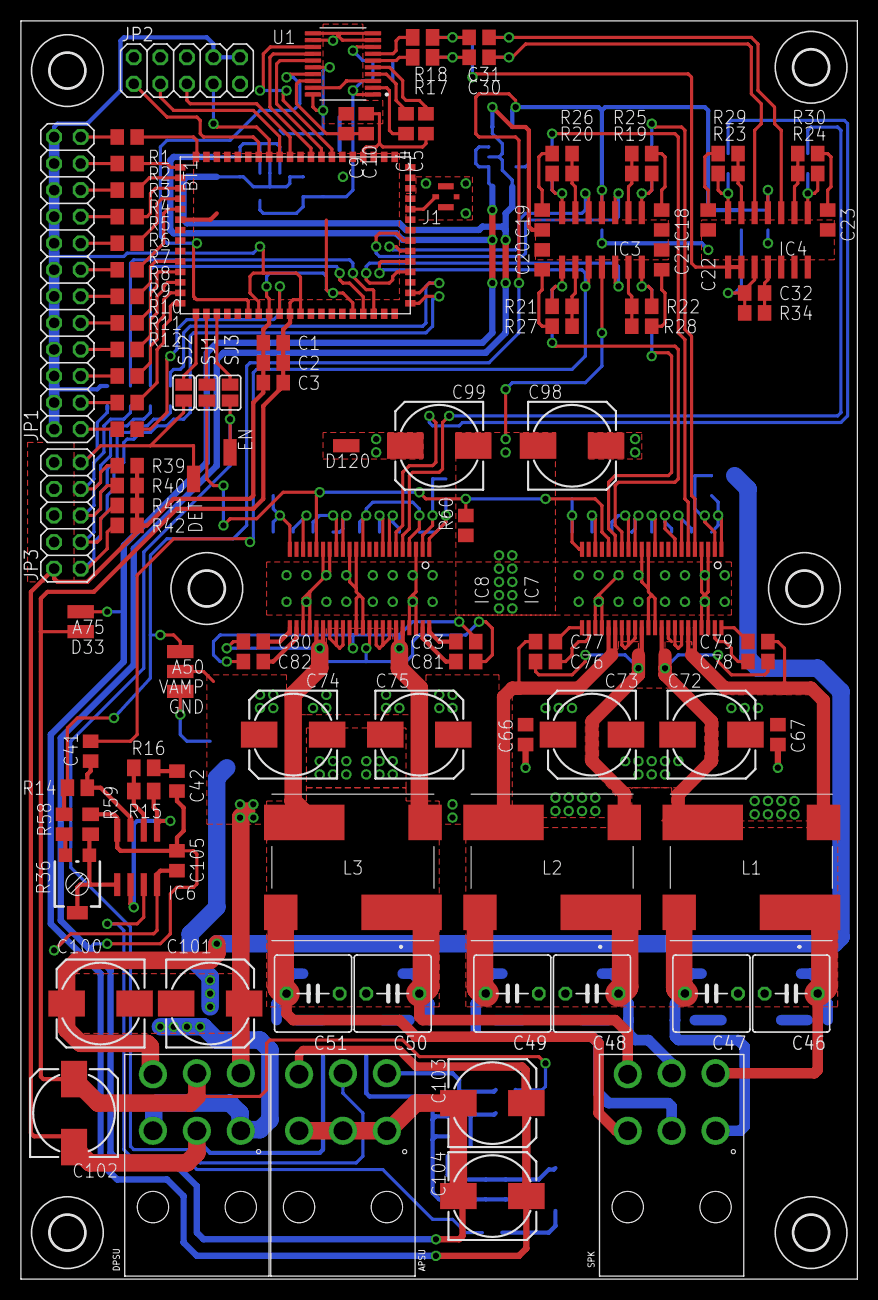
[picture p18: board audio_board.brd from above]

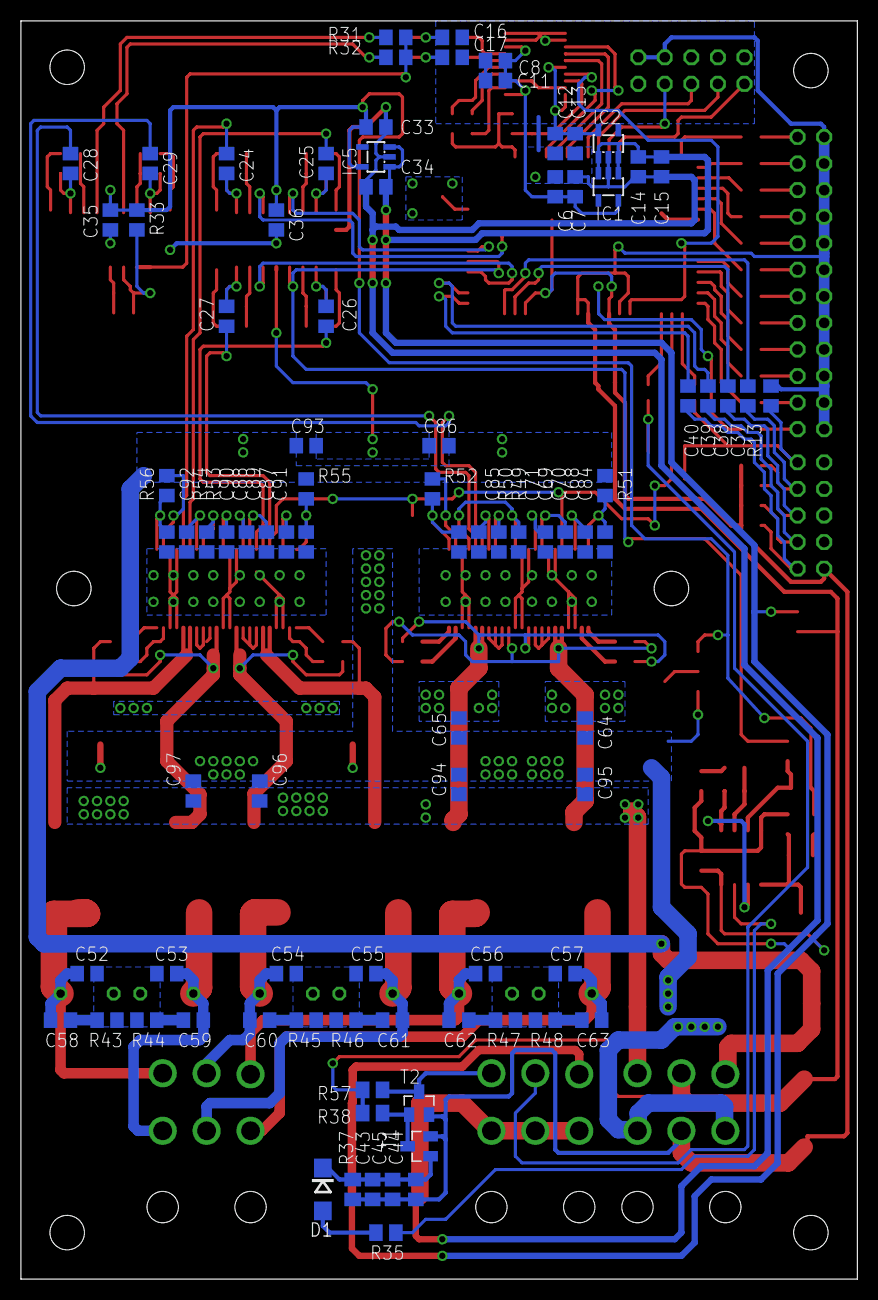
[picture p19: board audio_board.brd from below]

Board: 2 copper layers, 80.0 x 120.3 mm, 205 parts (87 on the bottom side), 148 nets.

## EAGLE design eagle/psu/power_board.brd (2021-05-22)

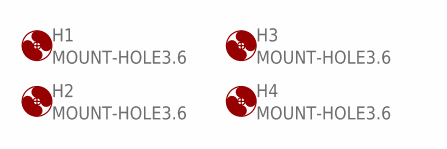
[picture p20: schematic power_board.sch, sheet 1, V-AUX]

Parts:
H1, H2, H3, H4: MOUNT-HOLE3.6; 3,6

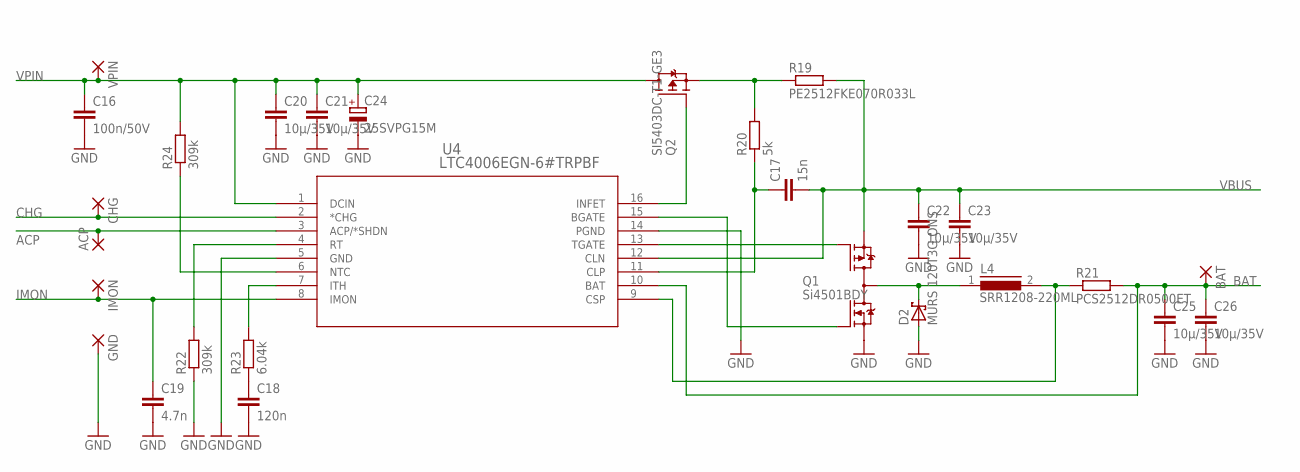
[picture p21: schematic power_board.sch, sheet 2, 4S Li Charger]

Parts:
ACP: SMD2; SMD1,27-2,54
BAT: SMD2; SMD1,27-2,54
C16: 100n/50V; C1206
C17: 15n; C0805
C18: 120n; C0805
C19: 4.7n; C0805
C20, C21, C22, C23, C25, C26: 10µ/35V; C1206
C24: 25SVPG15M; 153CLV-0505
CHG: SMD2; SMD1,27-2,54
D2: MURS 120T3G ONS; SMB
GND: SMD2; SMD1,27-2,54
IMON: SMD2; SMD1,27-2,54
L4: SRR1208-220ML; DR127
Q1: Si4501BDY; SO08-IRF
Q2: SI5403DC-T1-GE3; 1206-8CHIP-FET
R19: PE2512FKE070R033L; R2512
R20: 5k; R0805
R21: PCS2512DR0500ET; R2512
R22, R24: 309k; R0805
R23: 6.04k; R0805
U4: LTC4006EGN-6#TRPBF; SSOP-16_GN
VPIN: SMD2; SMD1,27-2,54

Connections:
ACP: ACP.1, U4.3 (ACP/*SHDN)
BAT: BAT.1, C25.1, C26.1, R21.2, U4.10 (BAT); also elsewhere on the board
CHG: CHG.1, U4.2 (*CHG)
GND: C16.2, C18.2, C19.2, C20.2, C21.2, C22.2, C23.2, C24.-, C25.2, C26.2, D2.A, GND.1, Q1.1 (N-S), R22.1, U4.5 (GND), U4.14 (PGND); also elsewhere on the board
IMON: C19.1, IMON.1, U4.8 (IMON)
unnamed: Q2.4 (G), U4.16 (INFET)
unnamed: Q2.5 (S), R19.1, R20.2
unnamed: Q1.4 (P-G), U4.13 (TGATE)
unnamed: Q1.2 (N-G), U4.15 (BGATE)
unnamed: C17.1, R20.1, U4.11 (CLP)
unnamed: C18.1, R23.1
unnamed: D2.C, L4.1, Q1.5 (D), Q1.6 (D), Q1.7 (D), Q1.8 (D)
unnamed: L4.2, R21.1, U4.9 (CSP)
unnamed: R22.2, U4.4 (RT)
unnamed: R23.2, U4.7 (ITH)
unnamed: R24.1, U4.6 (NTC)
VBUS: C17.2, C22.1, C23.1, Q1.3 (P-S), R19.2, U4.12 (CLN); also elsewhere on the board
VPIN: C16.1, C20.1, C21.1, C24.+, Q2.1 (D), Q2.2 (D), Q2.3 (D), Q2.6 (D), Q2.7 (D), Q2.8 (D), R24.2, U4.1 (DCIN), VPIN.1; also elsewhere on the board

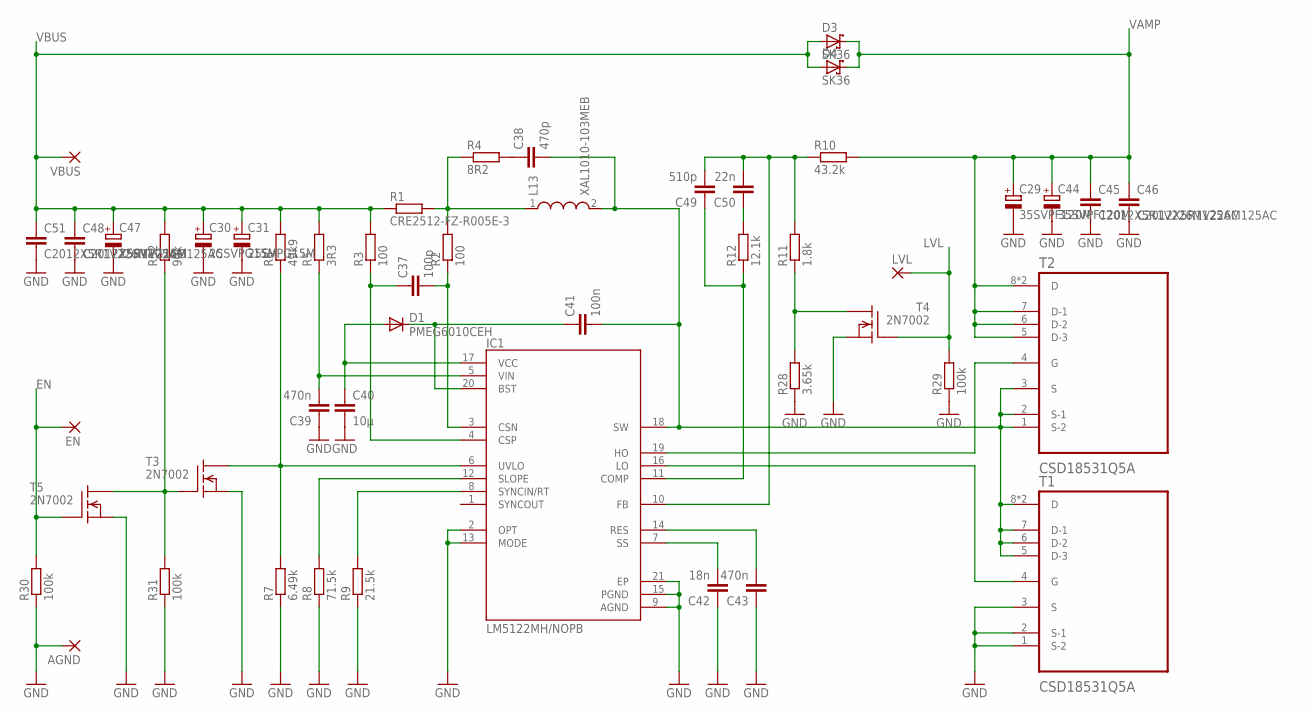
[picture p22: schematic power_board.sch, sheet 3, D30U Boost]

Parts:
AGND: SMD2; SMD1,27-2,54
C29, C44: 35SVPF120M; 153CLV-1012
C30, C31, C47: 25SVPG15M; 153CLV-0505
C37: 100p; C0805
C38: 470p; C0805
C39, C43: 470n; C0805
C40: 10µ; C1206
C41: 100n; C0805
C42: 18n; C0805
C45, C46, C48, C51: C2012X5R1V226M125AC; C0805
C49: 510p; C0805
C50: 22n; C0805
D1: PMEG6010CEH; SOD323-W
D3, D4: SK36; SMB
EN: SMD2; SMD1,27-2,54
IC1: LM5122MH/NOPB; SOP65P640X110-21N
L13: XAL1010-103MEB; INDC110100X1000N
LVL: SMD2; SMD1,27-2,54
R1: CRE2512-FZ-R005E-3; R2512
R2, R3: 100; R0805
R4: 8R2; M0805
R5: 3R3; R0805
R6: 49k9; R0805
R7: 6.49k; R0805
R8: 71.5k; R0805
R9: 21.5k; R0805
R10: 43.2k; R0805
R11: 1.8k; R0805
R12: 12.1k; R0805
R28: 3.65k; R0805
R29, R30, R31: 100k; R0805
R32: 90k; R0805
T1, T2: CSD18531Q5A; MOSFET_CSD19531Q5A
T3, T4, T5: 2N7002; SOT23
VBUS: SMD2; SMD1,27-2,54

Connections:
EN: EN.1, R30.2, T5.1 (G); also elsewhere on the board
GND: AGND.1, C29.-, C30.-, C31.-, C39.1, C40.2, C42.1, C43.1, C44.-, C45.2, C46.2, C47.-, C48.2, C51.2, IC1.2 (OPT), IC1.9 (AGND), IC1.13 (MODE), IC1.15 (PGND), IC1.21 (EP), R7.1, R8.1, R9.1, R28.1, R29.1, R30.1, R31.1, T1.1 (S-2), T1.2 (S-1), T1.3 (S), T3.2 (S), T4.2 (S), T5.2 (S); also elsewhere on the board
LVL: LVL.1, R29.2, T4.1 (G); also elsewhere on the board
unnamed: R11.1, R28.2, T4.3 (D)
unnamed: R31.2, R32.1, T3.1 (G), T5.3 (D)
unnamed: C38.2, C41.2, IC1.18 (SW), L13.2, T1.5 (D-3), T1.6 (D-2), T1.7 (D-1), T1.8 (D), T1.9 (D), T2.1 (S-2), T2.2 (S-1), T2.3 (S)
unnamed: C41.1, D1.C, IC1.20 (BST)
unnamed: L13.1, R1.2, R2.2, R4.1
unnamed: C38.1, R4.2
unnamed: C37.2, IC1.3 (CSN), R2.1
unnamed: C37.1, IC1.4 (CSP), R3.1
unnamed: IC1.19 (HO), T2.4 (G)
unnamed: IC1.16 (LO), T1.4 (G)
unnamed: C39.2, IC1.5 (VIN), R5.1
unnamed: C40.1, D1.A, IC1.17 (VCC)
unnamed: IC1.6 (UVLO), R6.1, R7.2, T3.3 (D)
unnamed: IC1.12 (SLOPE), R8.2
unnamed: IC1.8 (SYNCIN/RT), R9.2
unnamed: C42.2, IC1.7 (SS)
unnamed: C43.2, IC1.14 (RES)
unnamed: C49.2, C50.2, IC1.10 (FB), R10.1, R11.2
unnamed: C50.1, R12.2
unnamed: C49.1, IC1.11 (COMP), R12.1
VAMP: C29.+, C44.+, C45.1, C46.1, D3.C, D4.C, R10.2, T2.5 (D-3), T2.6 (D-2), T2.7 (D-1), T2.8 (D), T2.9 (D); also elsewhere on the board
VBUS: C30.+, C31.+, C47.+, C48.1, C51.1, D3.A, D4.A, R1.1, R3.2, R5.2, R6.2, R32.2, VBUS.1; also elsewhere on the board

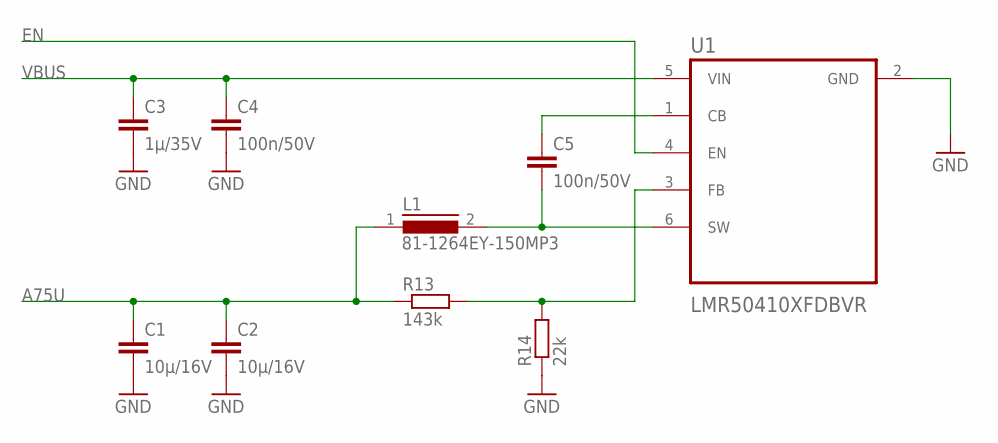
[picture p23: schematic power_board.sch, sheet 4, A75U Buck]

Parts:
C1, C2: 10µ/16V; C1206
C3: 1µ/35V; C1206
C4, C5: 100n/50V; C1206
L1: 81-1264EY-150MP3; DR73
R13: 143k; M0805
R14: 22k; M0805
U1: LMR50410XFDBVR; SOT95P280X145-6N

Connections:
A75U: C1.1, C2.1, L1.1, R13.1; also elsewhere on the board
EN: U1.4 (EN); also elsewhere on the board
GND: C1.2, C2.2, C3.2, C4.2, R14.1, U1.2 (GND); also elsewhere on the board
unnamed: C5.1, U1.1 (CB)
unnamed: C5.2, L1.2, U1.6 (SW)
unnamed: R13.2, R14.2, U1.3 (FB)
VBUS: C3.1, C4.1, U1.5 (VIN); also elsewhere on the board


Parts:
C6, C7: 10µ/16V; C1206
C8: 1µ/35V; C1206
C9, C10: 100n/50V; C1206
L2: 81-1264EY-150MP3; DR73
R15: 51k; M0805
R16: 22k; M0805
U2: LMR50410XFDBVR; SOT95P280X145-6N

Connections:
D33U: C6.1, C7.1, L2.1, R15.1; also elsewhere on the board
GND: C6.2, C7.2, C8.2, C9.2, R16.1, U2.2 (GND); also elsewhere on the board
unnamed: C10.1, U2.1 (CB)
unnamed: C10.2, L2.2, U2.6 (SW)
unnamed: R15.2, R16.2, U2.3 (FB)
VBUS: C8.1, C9.1, U2.4 (EN), U2.5 (VIN); also elsewhere on the board


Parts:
C11, C12: 10µ/16V; C1206
C13: 1µ/35V; C1206
C14, C15: 100n/50V; C1206
L3: 81-1264EY-150MP3; DR73
R17: 243k; M0805
R18: 22k; M0805
U3: LMR50410XFDBVR; SOT95P280X145-6N

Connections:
D120U: C11.1, C12.1, L3.1, R17.1; also elsewhere on the board
EN: U3.4 (EN); also elsewhere on the board
GND: C11.2, C12.2, C13.2, C14.2, R18.1, U3.2 (GND); also elsewhere on the board
unnamed: C15.1, U3.1 (CB)
unnamed: C15.2, L3.2, U3.6 (SW)
unnamed: R17.2, R18.2, U3.3 (FB)
VBUS: C13.1, C14.1, U3.5 (VIN); also elsewhere on the board

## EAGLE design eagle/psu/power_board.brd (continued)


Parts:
C27, C28, C32, C33, C34, C35: 10µ/16V; C1206
CN1: BAT+PSU; 5569_6P
CN2, CN3: 39-30-1060_BLANK; 5569_6P
L5, L6, L7: 81-1264EY-150MP3; DR73
R25: BELFUSE 430024; R1206W

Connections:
A75U: L5.1; also elsewhere on the board
BAT: CN1.P$1 (1), CN1.P$2 (2); also elsewhere on the board
D33U: L7.1; also elsewhere on the board
D120U: L6.1; also elsewhere on the board
EN: CN3.P$5 (5); also elsewhere on the board
GND: C27.2, C28.2, C32.2, C33.2, C34.2, C35.2, CN1.P$4 (4), CN1.P$5 (5), CN1.P$6 (6), CN2.P$1 (1), CN2.P$2 (2), CN2.P$3 (3), CN3.P$1 (1), CN3.P$2 (2), CN3.P$3 (3); also elsewhere on the board
LVL: CN3.P$6 (6); also elsewhere on the board
unnamed: CN1.P$3 (3), R25.1
unnamed: C27.1, C28.1, CN3.P$4 (4), L5.2
unnamed: C34.1, C35.1, CN2.P$4 (4), L6.2
unnamed: C32.1, C33.1, CN2.P$5 (5), L7.2
VAMP: CN2.P$6 (6); also elsewhere on the board
VPIN: R25.2; also elsewhere on the board


Board: 2 copper layers, 79.4 x 100.0 mm, 121 parts (0 on the bottom side), 57 nets.

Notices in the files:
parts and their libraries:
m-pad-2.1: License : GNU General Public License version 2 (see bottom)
